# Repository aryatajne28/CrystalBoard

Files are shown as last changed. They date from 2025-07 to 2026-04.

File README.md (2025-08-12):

# CrystalBoard

## A Mechanical Keyboard with clear acrylic case
I always wanted to make a mechanical keyboard using some stacked transparent Acrylic Sheets.
- It now has per key RGB Lights.
- Featuring a Stacked Acrylic Case with minimalistic design.

## Overall CAD Design:
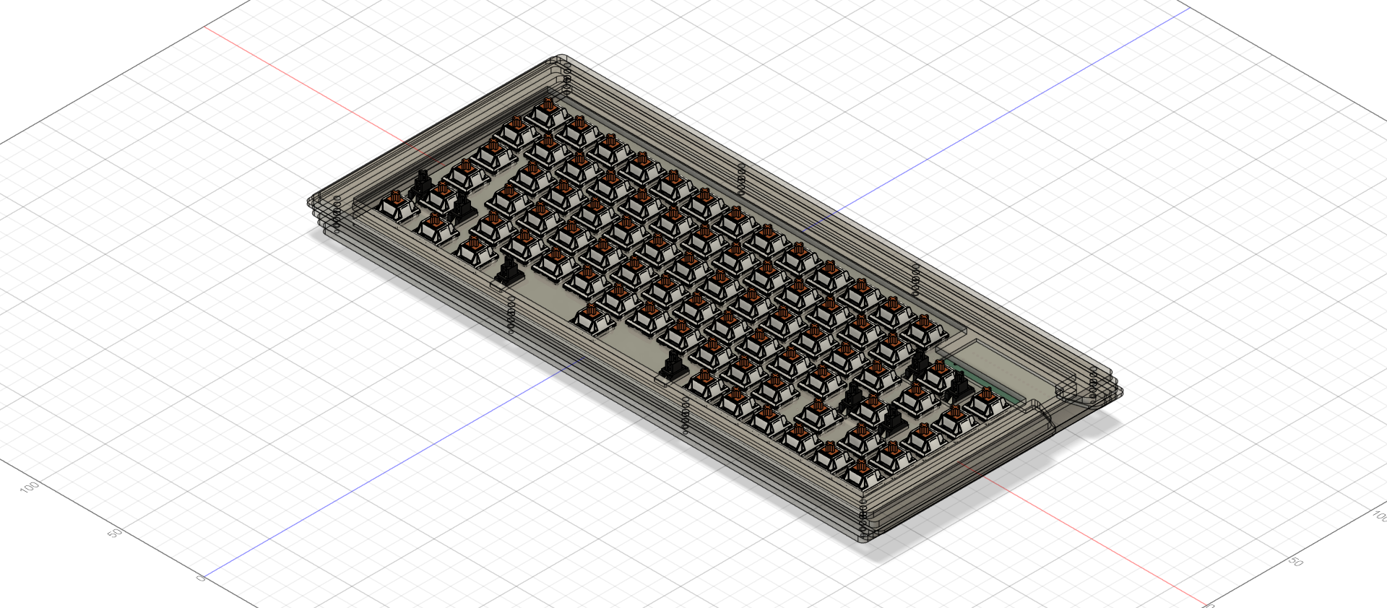
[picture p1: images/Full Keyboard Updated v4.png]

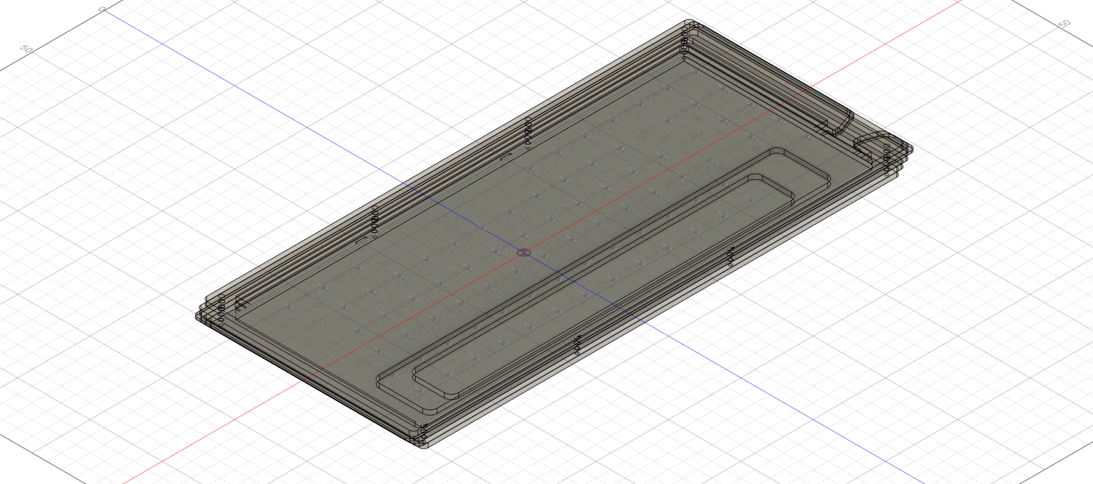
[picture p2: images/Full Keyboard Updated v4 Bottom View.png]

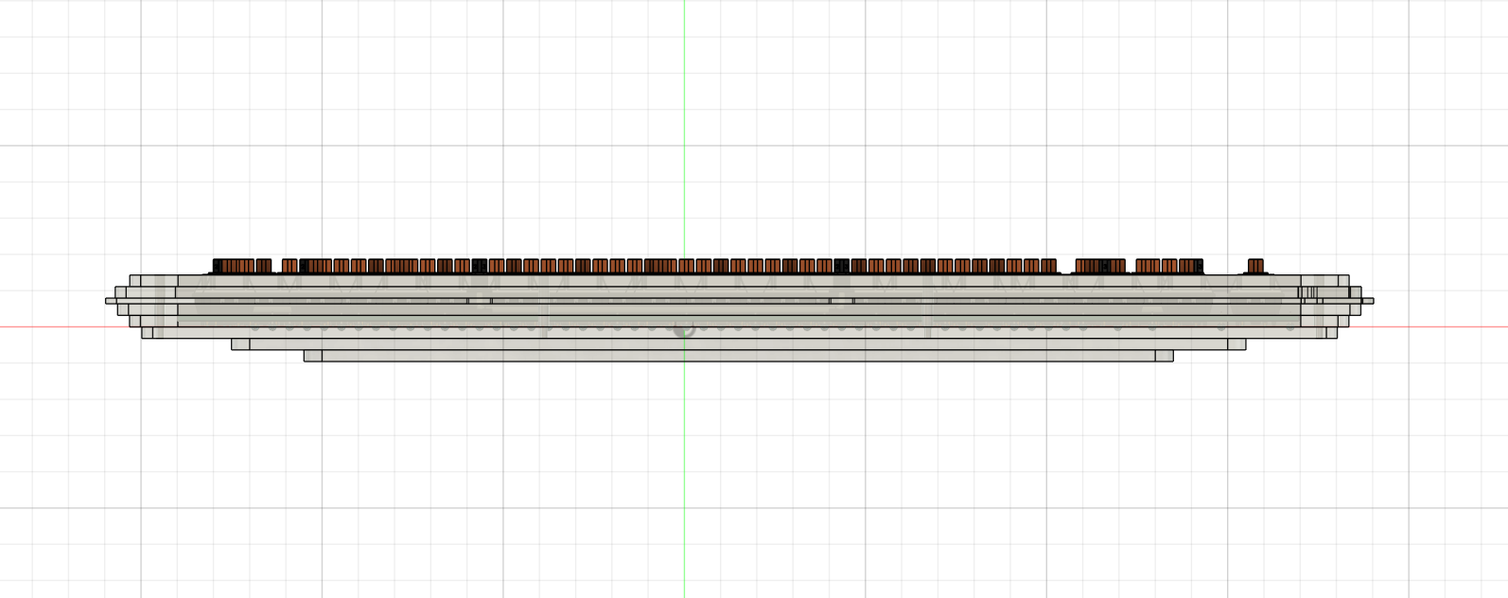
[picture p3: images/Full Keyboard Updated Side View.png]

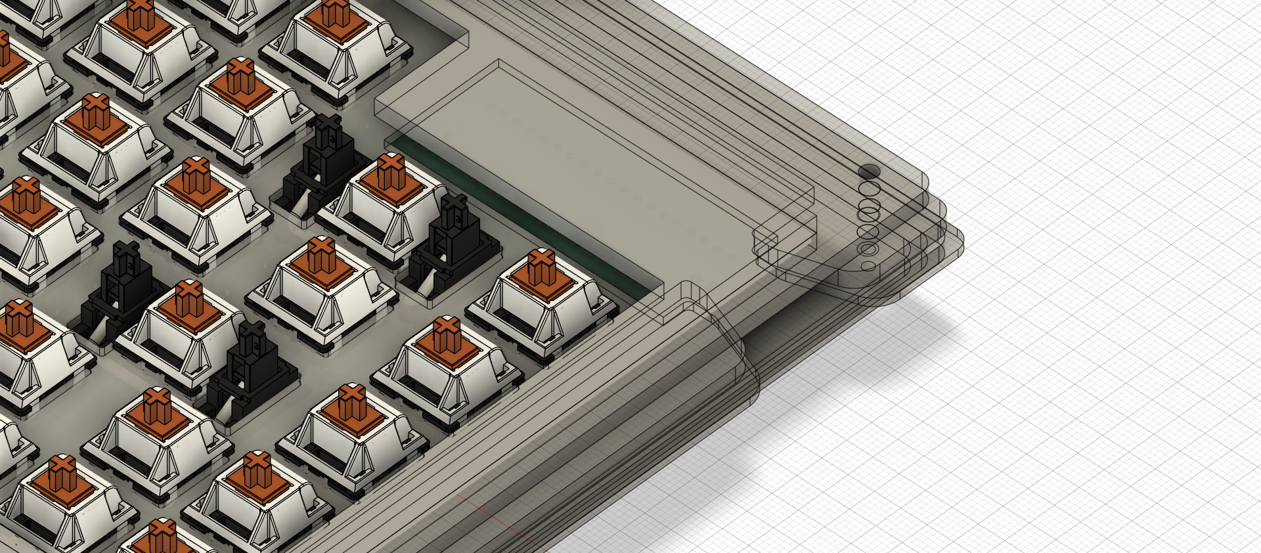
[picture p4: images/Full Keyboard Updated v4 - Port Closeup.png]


## PCB Design
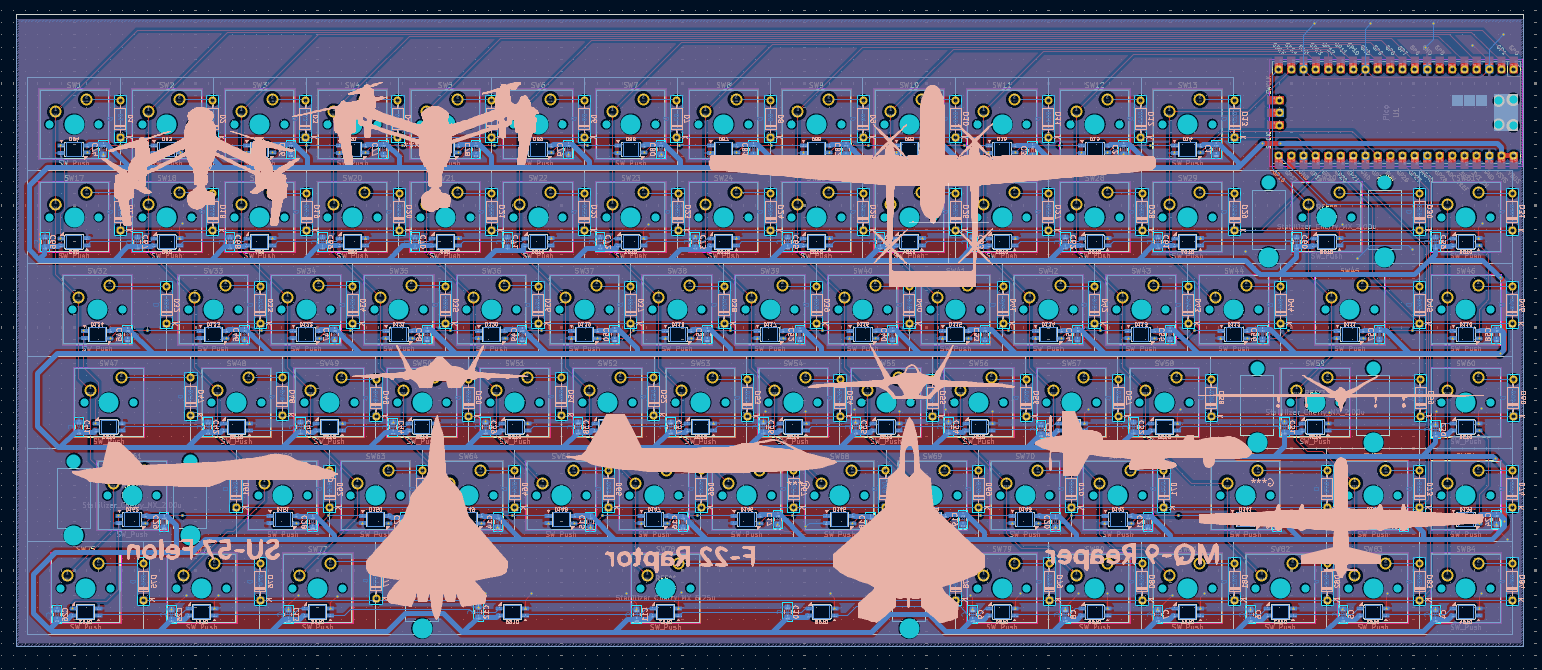
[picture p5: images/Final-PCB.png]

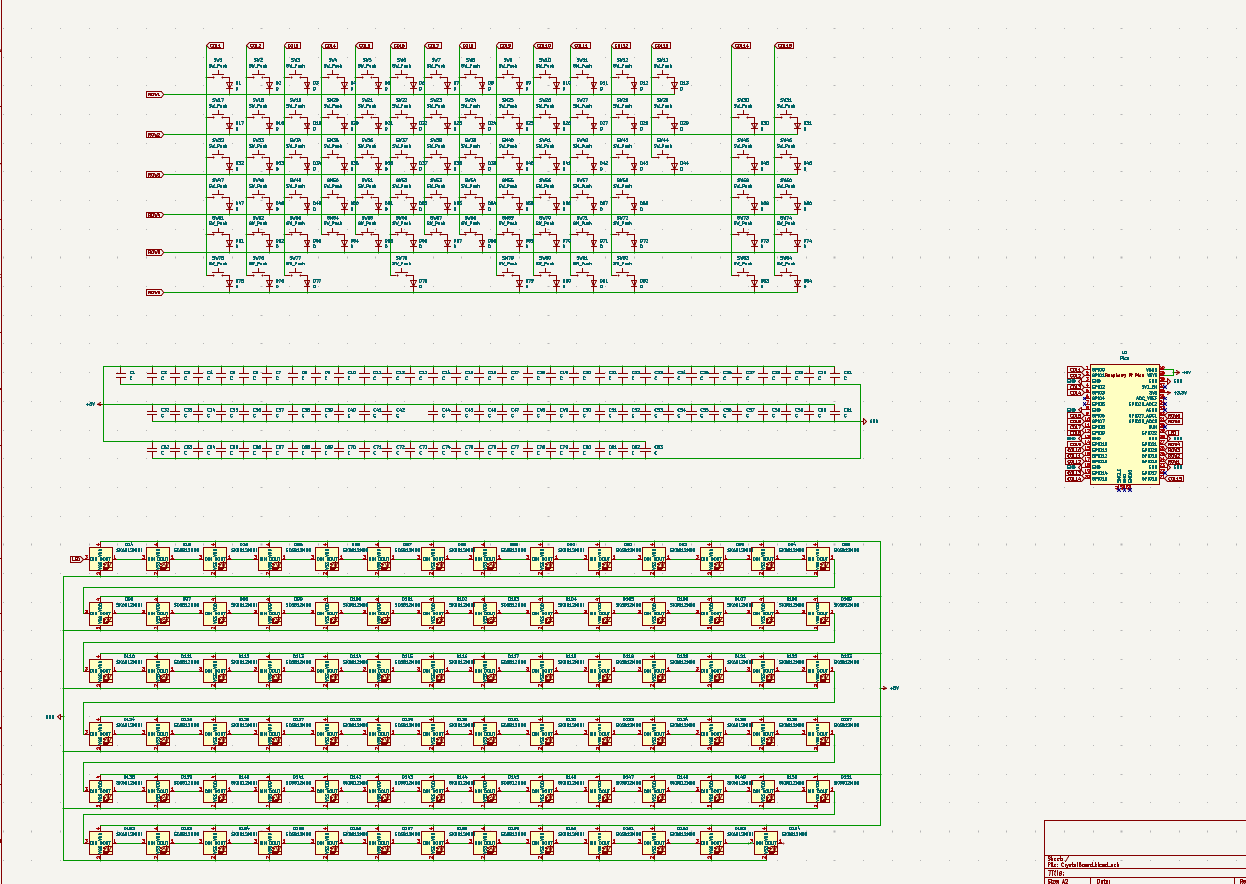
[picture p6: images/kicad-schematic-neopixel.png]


##  BOM List:
https://docs.google.com/spreadsheets/d/18xa4JLoS0O1zEA5zLQhojN7E5wao-EmZjV8RXe0JSpA/
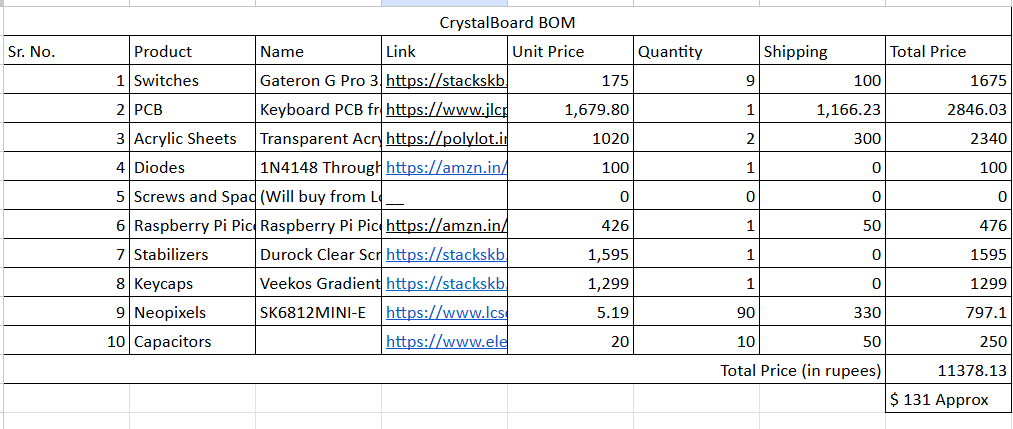
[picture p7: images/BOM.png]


- The CAD output is not what it will look like in real life, it will turn out really cool I can assure!

- Total Time Spent: 16 hours!

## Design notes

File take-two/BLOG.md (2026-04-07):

# My experience with making of the CrystalBoard.

## Assembly
First let's go through the assembly and making of CrystalBoard
- I had cut the acrylic sheets from my school's laser cutter.
- So, I layed out some of the switches onto the acrylic plate to check whether it cutouts match with the PCB or not.

|   |  | |
| - | - | -|

- Since they were matching, I went ahead and soldered the Pi Pico to my PCB and screwed in the stablizers.

|  |   |
| - | - |

- Thus, the next step I did was to solder all the switches and rest of the components in the back of the PCB!

||  |
| - | - |

- After this, I was about to solder my Neopixels, then I noticed that the pins are not matching. I quickly opened my Kicad file and checked and whoosh! I used the wrong footprint :)
- Thus, I was left with no choice but to assemble without them! And after assembling all the rest of the sheets and keycaps, we have our Crystalboard:

|  |  |
| -|-|

## Firmware
I used QMK for this, since I consider it to be a very standard firmware for it's features like: the keyboard isn't detected as a new USB device everytime we plug it in
and direct build loading onto our MCU!

## Why this project didn't work?
- Used wrong footprint for Neopixels (sk6812mini instead of sk6812mini-e).
- I didn't calculate the placement of Micro-USB port of Pico, and due to which, the USB-port broke-off from the pico after short usage while flashing the firmware!
- I didn't have tolerances for screws holes I made in acrylic sheet, due to which the screws didn't go through, I had to use glue temporarily.

## My two cents for anyone designing a keyboard!
- Maybe try to design a hotswappable design. Because for soldering the switches, you have to first insert the switches through the plate that you will design. So if you want to desolder even one switch, that will become a nightmare!
- Focus very much on the CAD of case design, cause even a slight mis-alignment won't let your PCB fit in!

Demo link: https://youtu.be/TqwXyUNoaCY
P.S. there's nothing much in there cause currently the keyboard is not working!

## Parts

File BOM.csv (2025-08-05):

CrystalBoard BOM
Sr. No. | Product | Name | Link | Unit Price | Quantity | Shipping | Total Price
1 | Switches | Gateron G Pro 3.0 Brown KS-9 Tactile Switch (Pack of 10) | https://stackskb.com/store/gateron-g-pro-3-0-brown-ks-9-tactile-switch-pack-of-10/ | 175 | 9 | 100 | 1675
2 | PCB | Keyboard PCB from JLCPCB | https://www.jlcpcb.com/ | 1,679.80 | 1 | 1,166.23 | 2846.03
3 | Acrylic Sheets | Transparent Acrylic Sheets 4ft * 2ft | https://polylot.in/online-store-acrylic-polycarbonate-sheet-buy-online-iindia/acrylicsheet/acrylic-sheets/ | 1020 | 2 | 300 | 2340
4 | Diodes | 1N4148 Through Holes | https://amzn.in/d/j3eLvoh | 100 | 1 | 0 | 100
5 | Screws and Spacers | (Will buy from Local Hardware Shop) | __ | 0 | 0 | 0 | 0
6 | Raspberry Pi Pico | Raspberry Pi Pico | https://amzn.in/d/0y7kWCl | 426 | 1 | 50 | 476
7 | Stabilizers | Durock Clear Screw-In Stabilizers V2 | https://stackskb.com/store/durock-smokey-screw-in-stabilizers-v2/ | 1,595 | 1 | 0 | 1595
8 | Keycaps | Veekos Gradient Keycaps (Cherry Profile) (135 keys) | https://stackskb.com/store/veekos-gradient-keycaps-cherry-profile-135-keys/ | 1,299 | 1 | 0 | 1299
9 | Neopixels | SK6812MINI-E | https://www.lcsc.com/product-detail/C5149201.html | 5.19 | 90 | 330 | 797.1
Total Price |  |  |  |  |  |  | 11128.13 | (in rupees)
 |  |  |  |  |  |  | $ 127 Approx

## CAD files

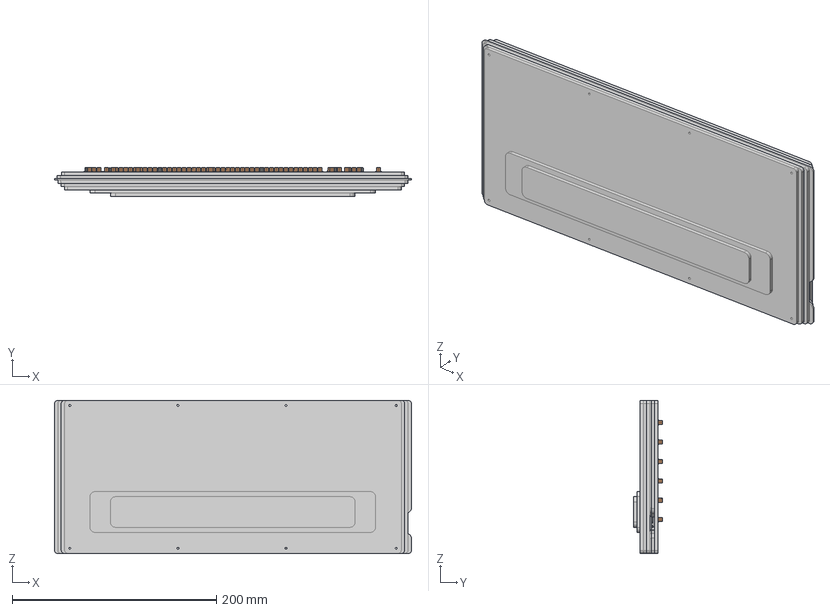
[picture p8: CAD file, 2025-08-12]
CAD/Full Keyboard Updated_.step
350.0 x 28.2 x 150.3 mm
SW_Cherry_MX_PCB x 81
Stabilizer_Cherry_MX_2.00u x 3
Stabilizer_Cherry_MX_6.25u
D_DO-35_SOD27_P7.62mm_Horizontal x 81

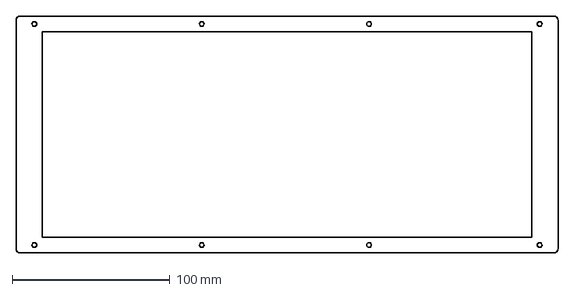
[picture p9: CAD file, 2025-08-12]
case/ClosedSpacerLevel2.dxf
343.2 x 150.0 mm

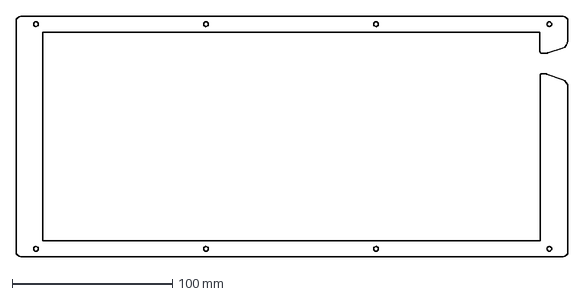
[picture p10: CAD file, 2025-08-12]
case/OpenSpacerLevel4.dxf
344.0 x 150.0 mm

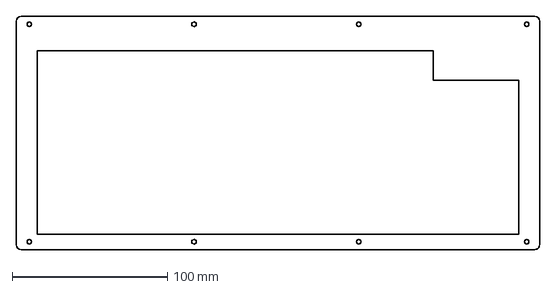
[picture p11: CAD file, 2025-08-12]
Production/LaserCutting/TopSpacerLevel6.dxf
336.6 x 150.0 mm

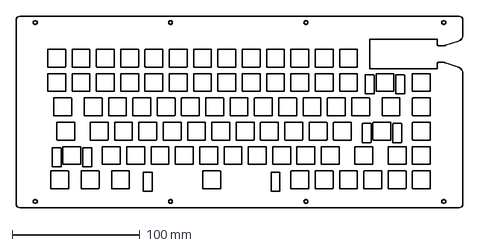
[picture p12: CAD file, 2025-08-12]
case/SwitchPlateV2.dxf
350.0 x 150.0 mm

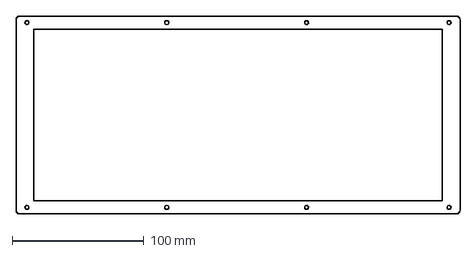
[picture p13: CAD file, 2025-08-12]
Production/LaserCutting/ClosedSpacerLevel1.dxf
336.6 x 150.0 mm

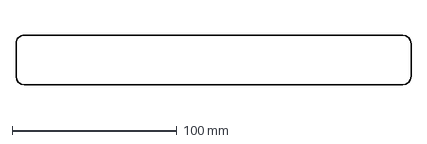
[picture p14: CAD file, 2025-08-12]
Production/LaserCutting/StandLevel0.dxf
240.0 x 30.0 mm

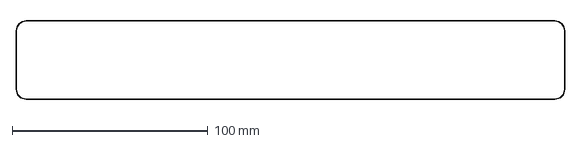
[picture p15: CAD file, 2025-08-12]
Production/LaserCutting/StandLevel1.dxf
280.0 x 40.0 mm

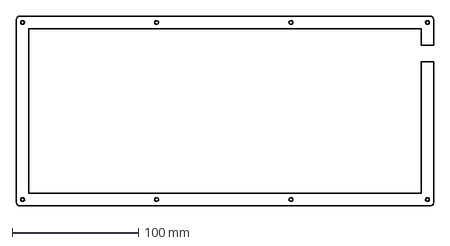
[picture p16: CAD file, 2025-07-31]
Production/LaserCutting/OpenSpacer.dxf
330.0 x 150.0 mm

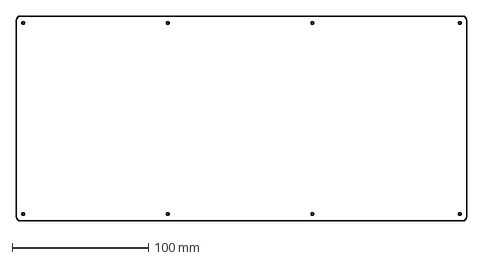
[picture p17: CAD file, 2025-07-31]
Production/LaserCutting/Bottom.dxf
330.0 x 150.0 mm

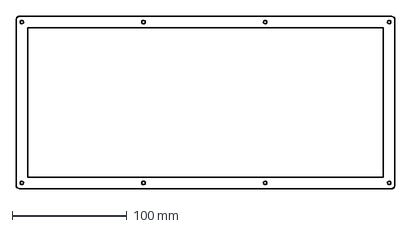
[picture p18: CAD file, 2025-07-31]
Production/LaserCutting/ClosedSpacer.dxf
330.0 x 150.0 mm

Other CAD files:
Production/LaserCutting/SwitchPlate.dxf

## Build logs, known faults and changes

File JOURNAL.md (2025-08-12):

# Journal for CrystalBoard

- Date 26/07/25 - Total Time Spent: 0.5 hours
    - Idea: Make a custom mechanical keyboard with case made up of clear acrylic sheets stacked on top of each other, thus the name crystal board!
    - Work done - Finalised the layout, took it from keyboard-layout-editor.com and drawn all the rows and columns on that layout!
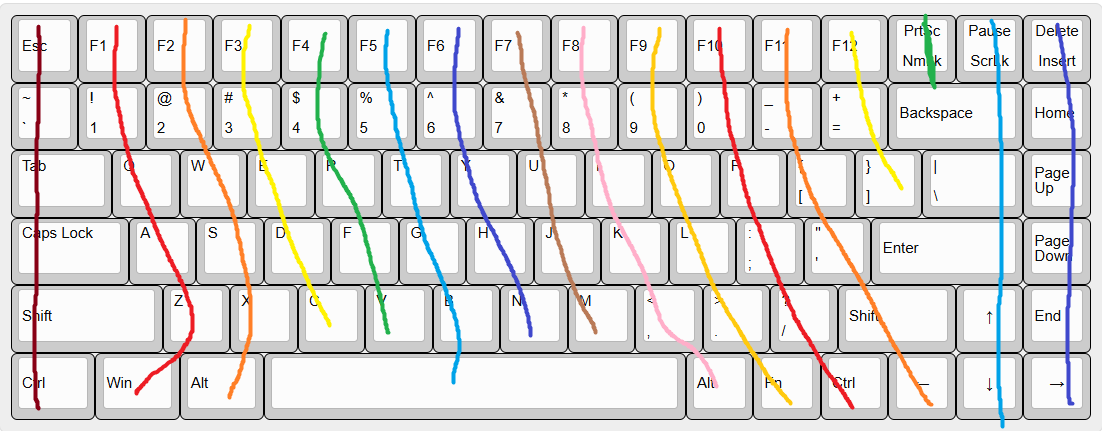
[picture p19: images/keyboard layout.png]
Keyboard Layout
    
    - Setup Kicad with all the libraries and footprints.
    - Time Spent - 30 mins
    
- Date 27/07/25 - Total Time Spent: 4.5 hours
    - I made the complete schematic made the PCB layout but then I noticed that there is no space for Pi Pico. So I deleted the top right 3 keys, thus I had to do changes in the Kicad Schematic and PCB. Thus took some time but I am done with PCB routing. Now I am thinking to add some neopixels and some silkscreen to the PCB.
    - The updated keyboard layout looks like this now:
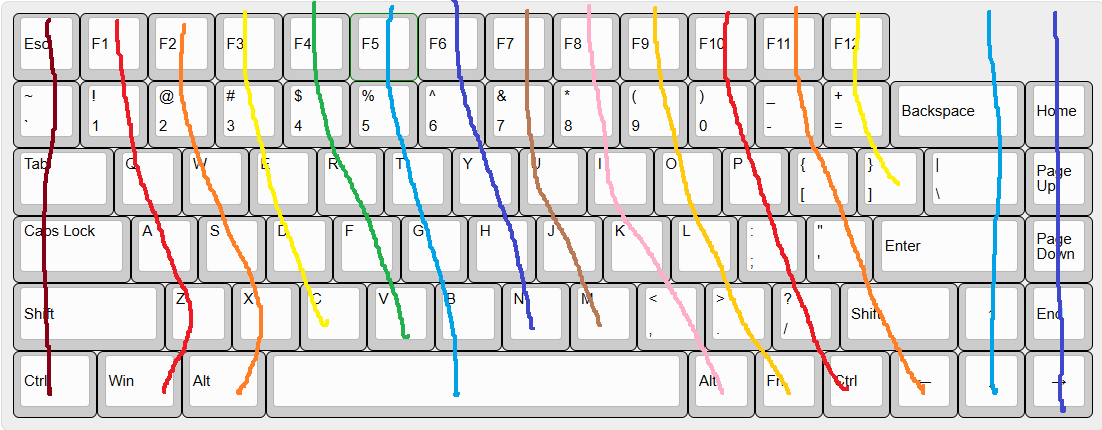
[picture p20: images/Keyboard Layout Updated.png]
Keyboard Layout Updated
    
    - Kicad Schematic and PCB:
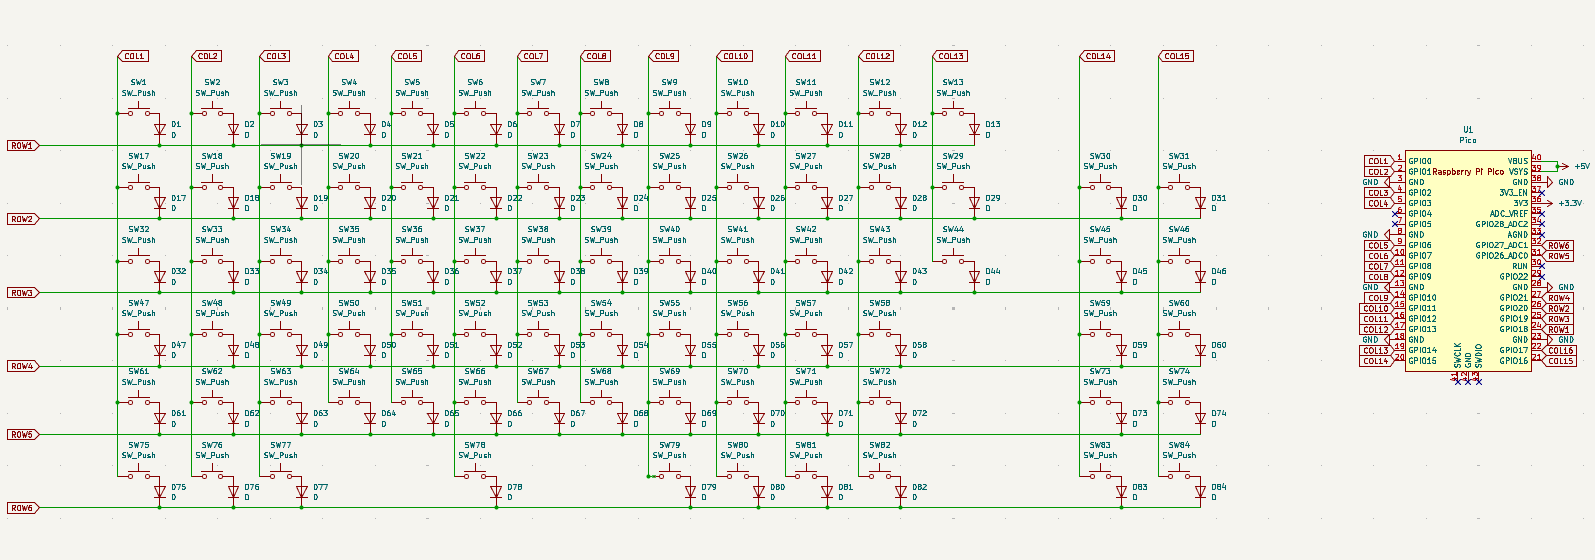
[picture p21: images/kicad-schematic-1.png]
Kicad Schematic
    
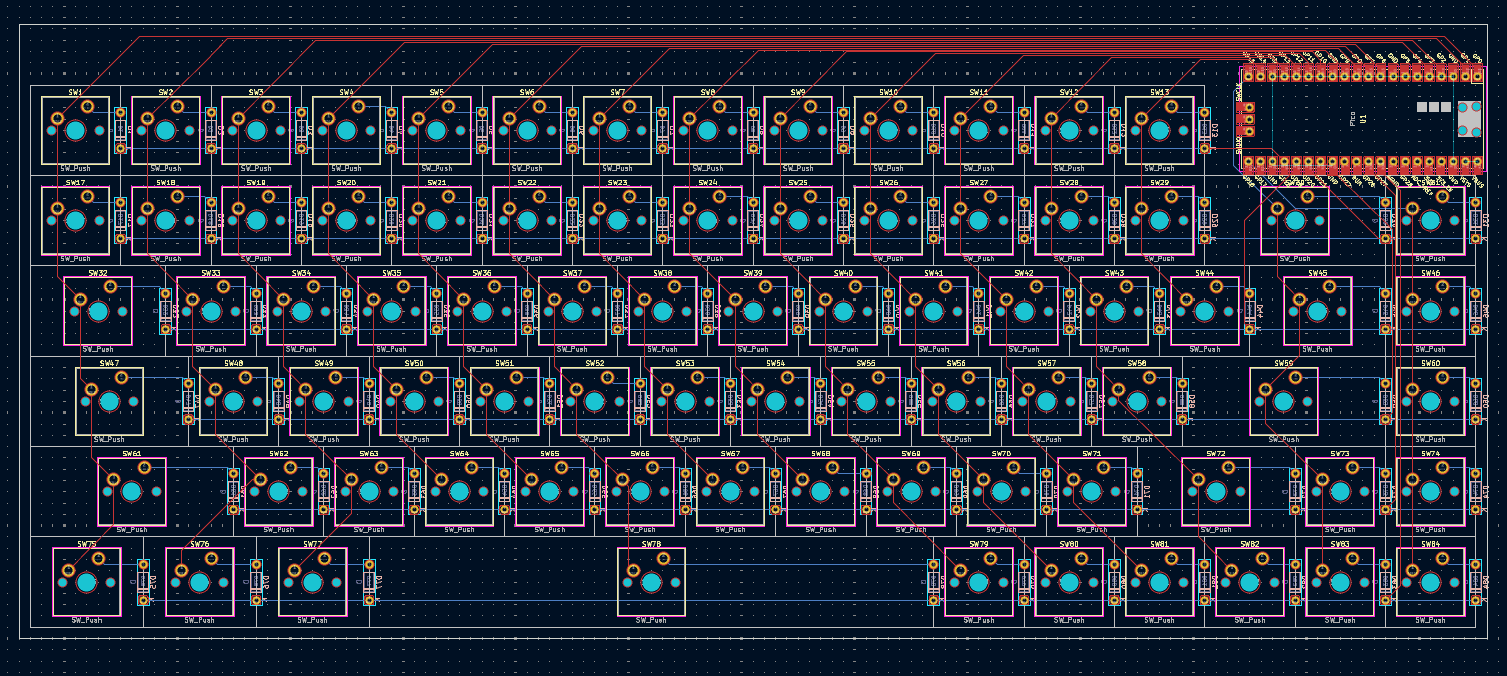
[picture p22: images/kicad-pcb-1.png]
Kicad PCB
    
    - Things to do next - Put some Neopixels, Stabilizers, Plate, Silkscreen
    - Time Spent today till now - 3 hours

- Date 27/07/25 (Update 2)
    - Done with the Neopixels, I did not add per key LED but a bar on top and on WASD keys (not for gaming obviously :O)
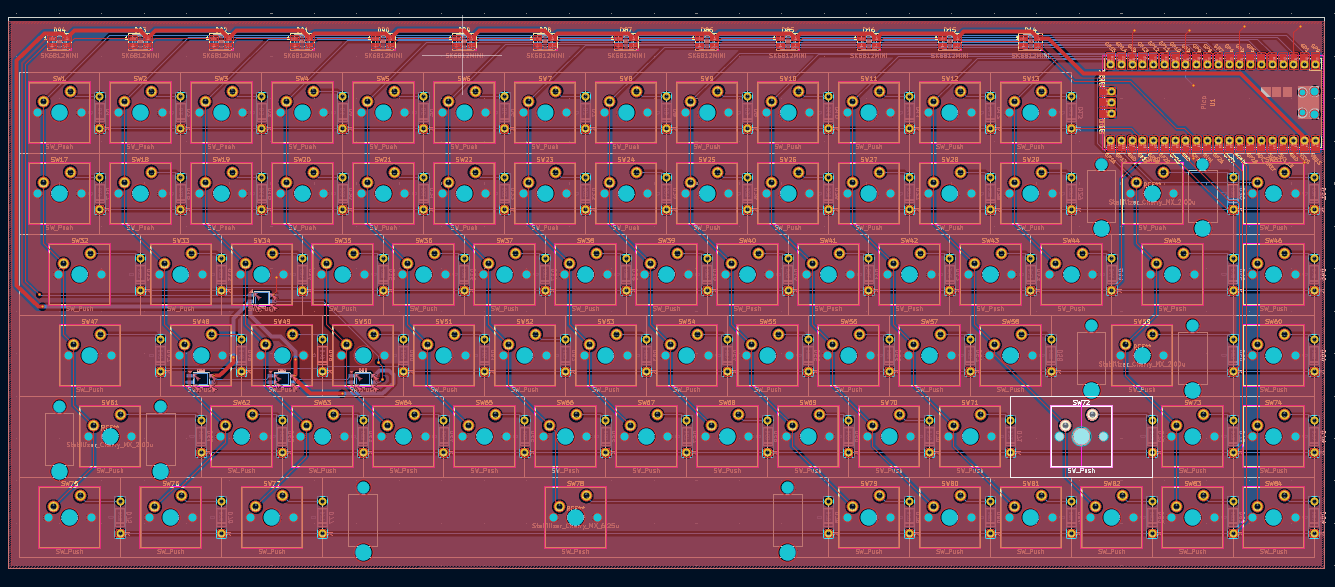
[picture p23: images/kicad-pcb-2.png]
    
    - Time Spent - 1.5 hours

- Date 28/07/25 - Total Time Spent: 1.5 hours
    - Done with Silkscreen and Stablizers.
    - It was pain to convert the images into B&W vectors.
    - PCB Looks like this now:
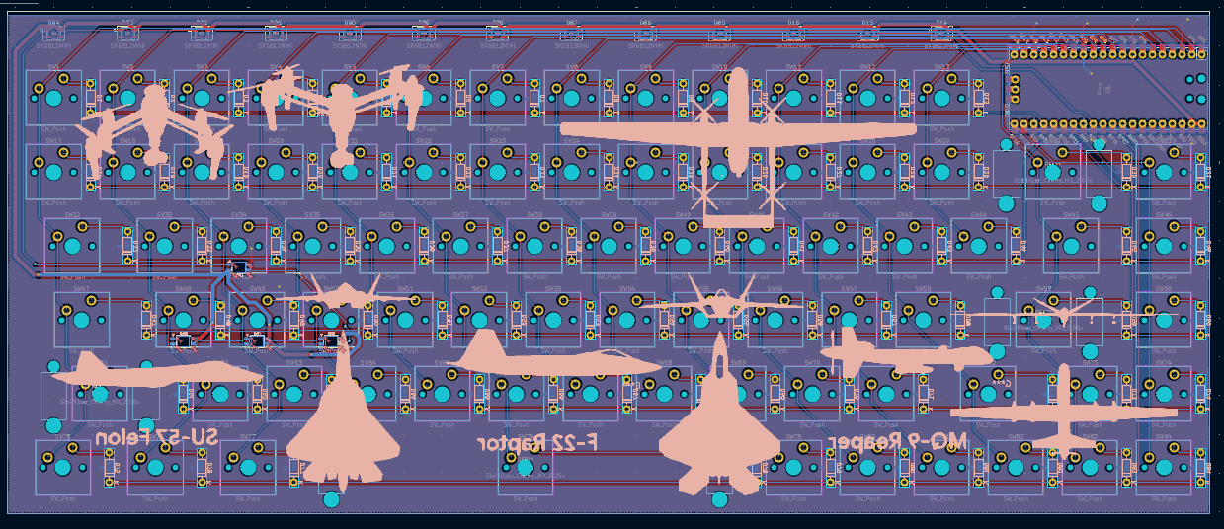
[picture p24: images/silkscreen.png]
    
    - Time spent - 1.5 hours

- Date 31/07/25 - Total Time Spent: 5 hours
    - Speedrunning the Case and Code File!
    - Case I have designed as layers since I will be laser cutting the acrylic sheets.
    - For illustration purposes I have just reduced the opacity of the components in Autocad to make it look like Acrylic, but in real life it will look really good!
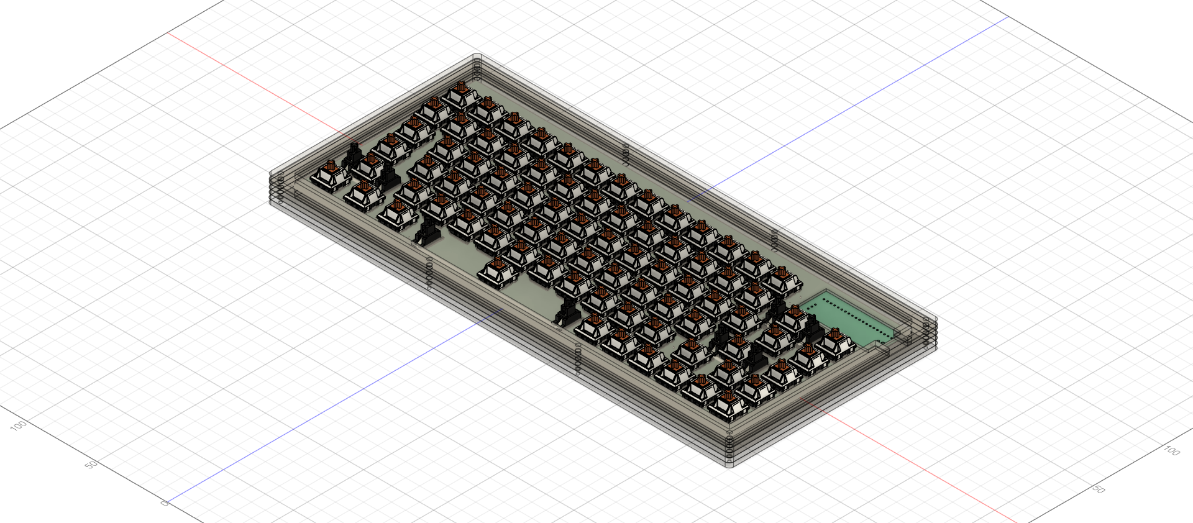
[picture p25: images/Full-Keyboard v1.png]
    
    - Time spent - 3 hours

    - Finalized the repo and collected resources for all the BOM.
    - Time Spent - 2 hours

- Date 03/08/25 - Total Time Spent: 2 hours
    - According to the changes suggested by @Kai Pereira(Slack) I have now added per key RGB Neopixel!
    - So I deleted all the tracks because it was a lot of hassle to shift everything and again route.
    - Added 83x Neopixels and 83x 0805 Capacitors in the schematic and now searching for good site to order from, because ordering to India is a hassle
    - New Schematic and PCB photo:
    
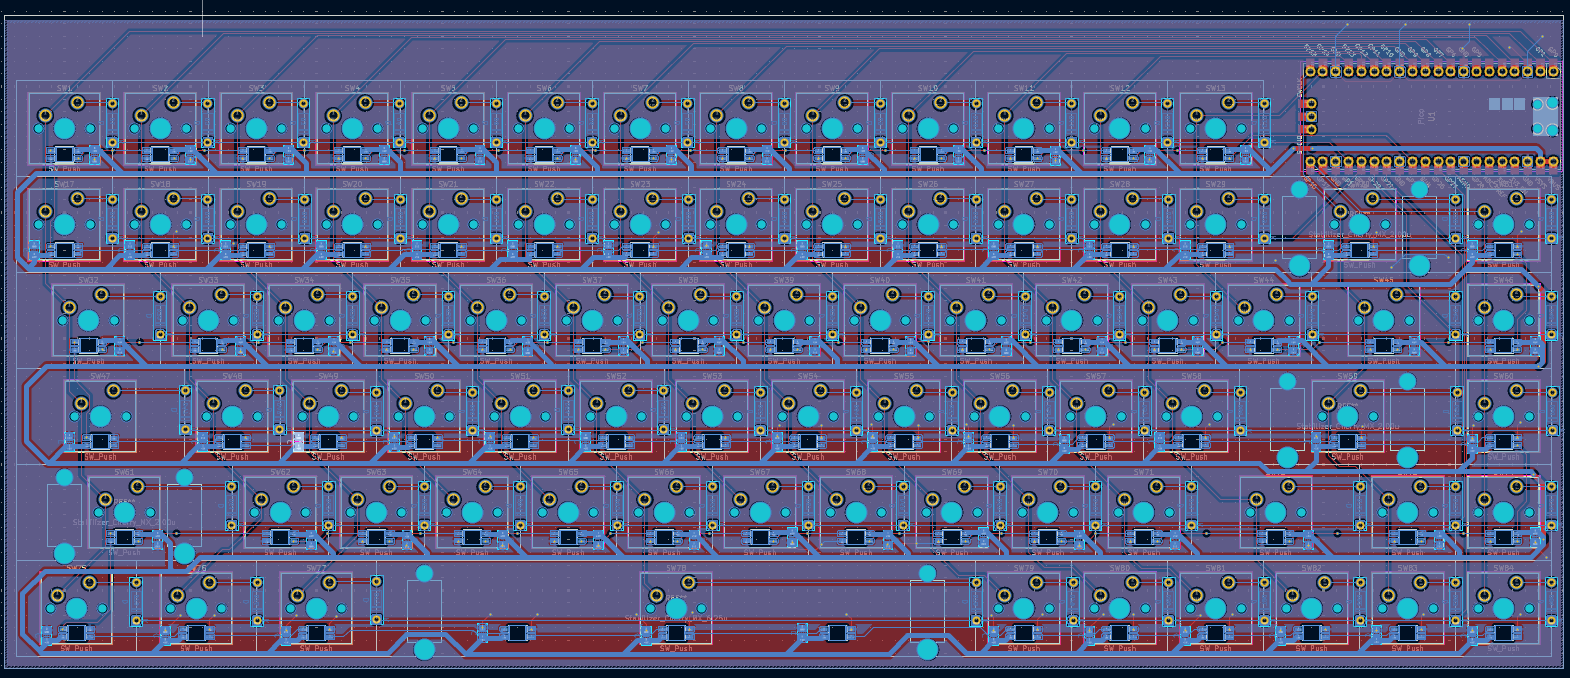
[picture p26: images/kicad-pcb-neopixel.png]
    
    - Todo: Code change and Update BOM
    - Time Spent - 2 hours

- Date 06/08/25 - Total Time Spent: 0.5 hours
    - I have added the updated items in my BOM and updated the code a bit.
    - Refinded the README.md file.
    - Another Update, I uploaded the new Kicad Project files and the production .zip folder for the same.
    - Time Spent - 0.5 hours

- Date 12/08/25 - Total Time Spent: 2 hours
    - According to the changes suggested by Kai, I have made the case a bit more complex.
    - I took referrence from this design I found online: https://www.ponoko.com/blog/maker-success-stories/limbo-keys-custom-mechanical-keyboards/
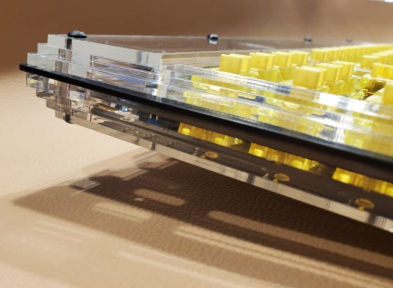
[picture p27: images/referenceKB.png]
    - Reference images: 
    - What I did in Fusion:
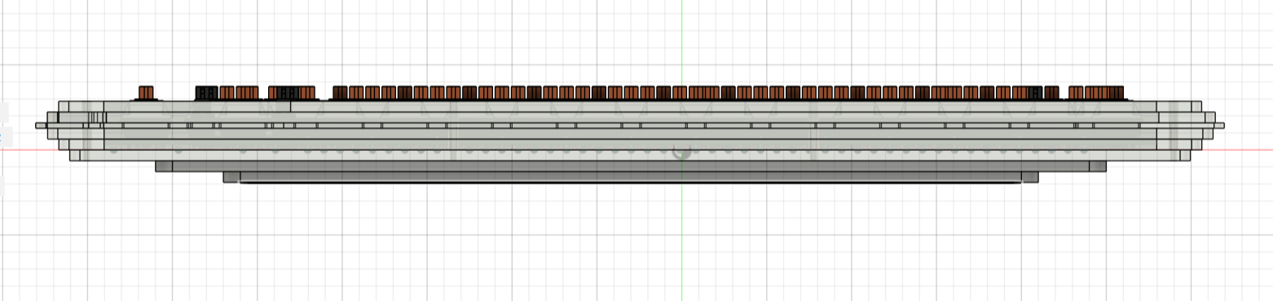
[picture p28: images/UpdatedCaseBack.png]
    
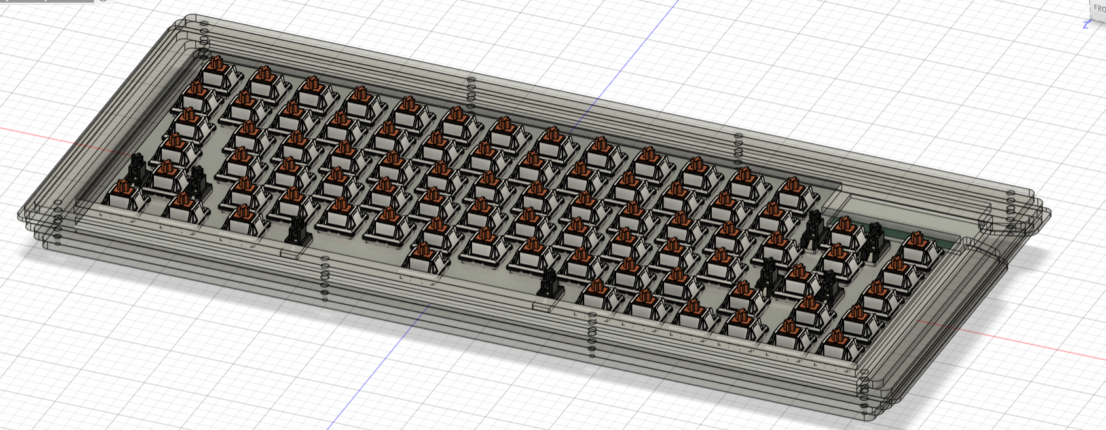
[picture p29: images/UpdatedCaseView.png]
    
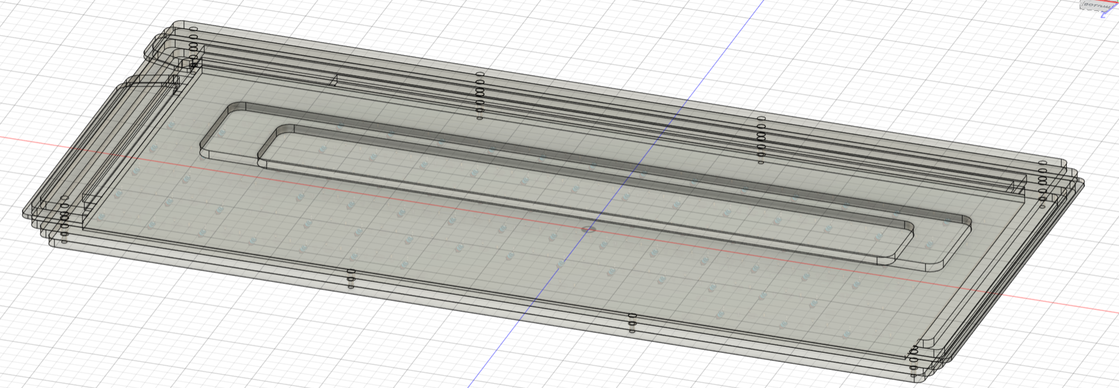
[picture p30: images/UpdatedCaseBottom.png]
    

    - Now it has a stand below for a tilted design, which is just two cutouts of leftover acrylic and I will stick them using clear glue.
    - BOM remains the same.
    - Time Spent - 2 hours

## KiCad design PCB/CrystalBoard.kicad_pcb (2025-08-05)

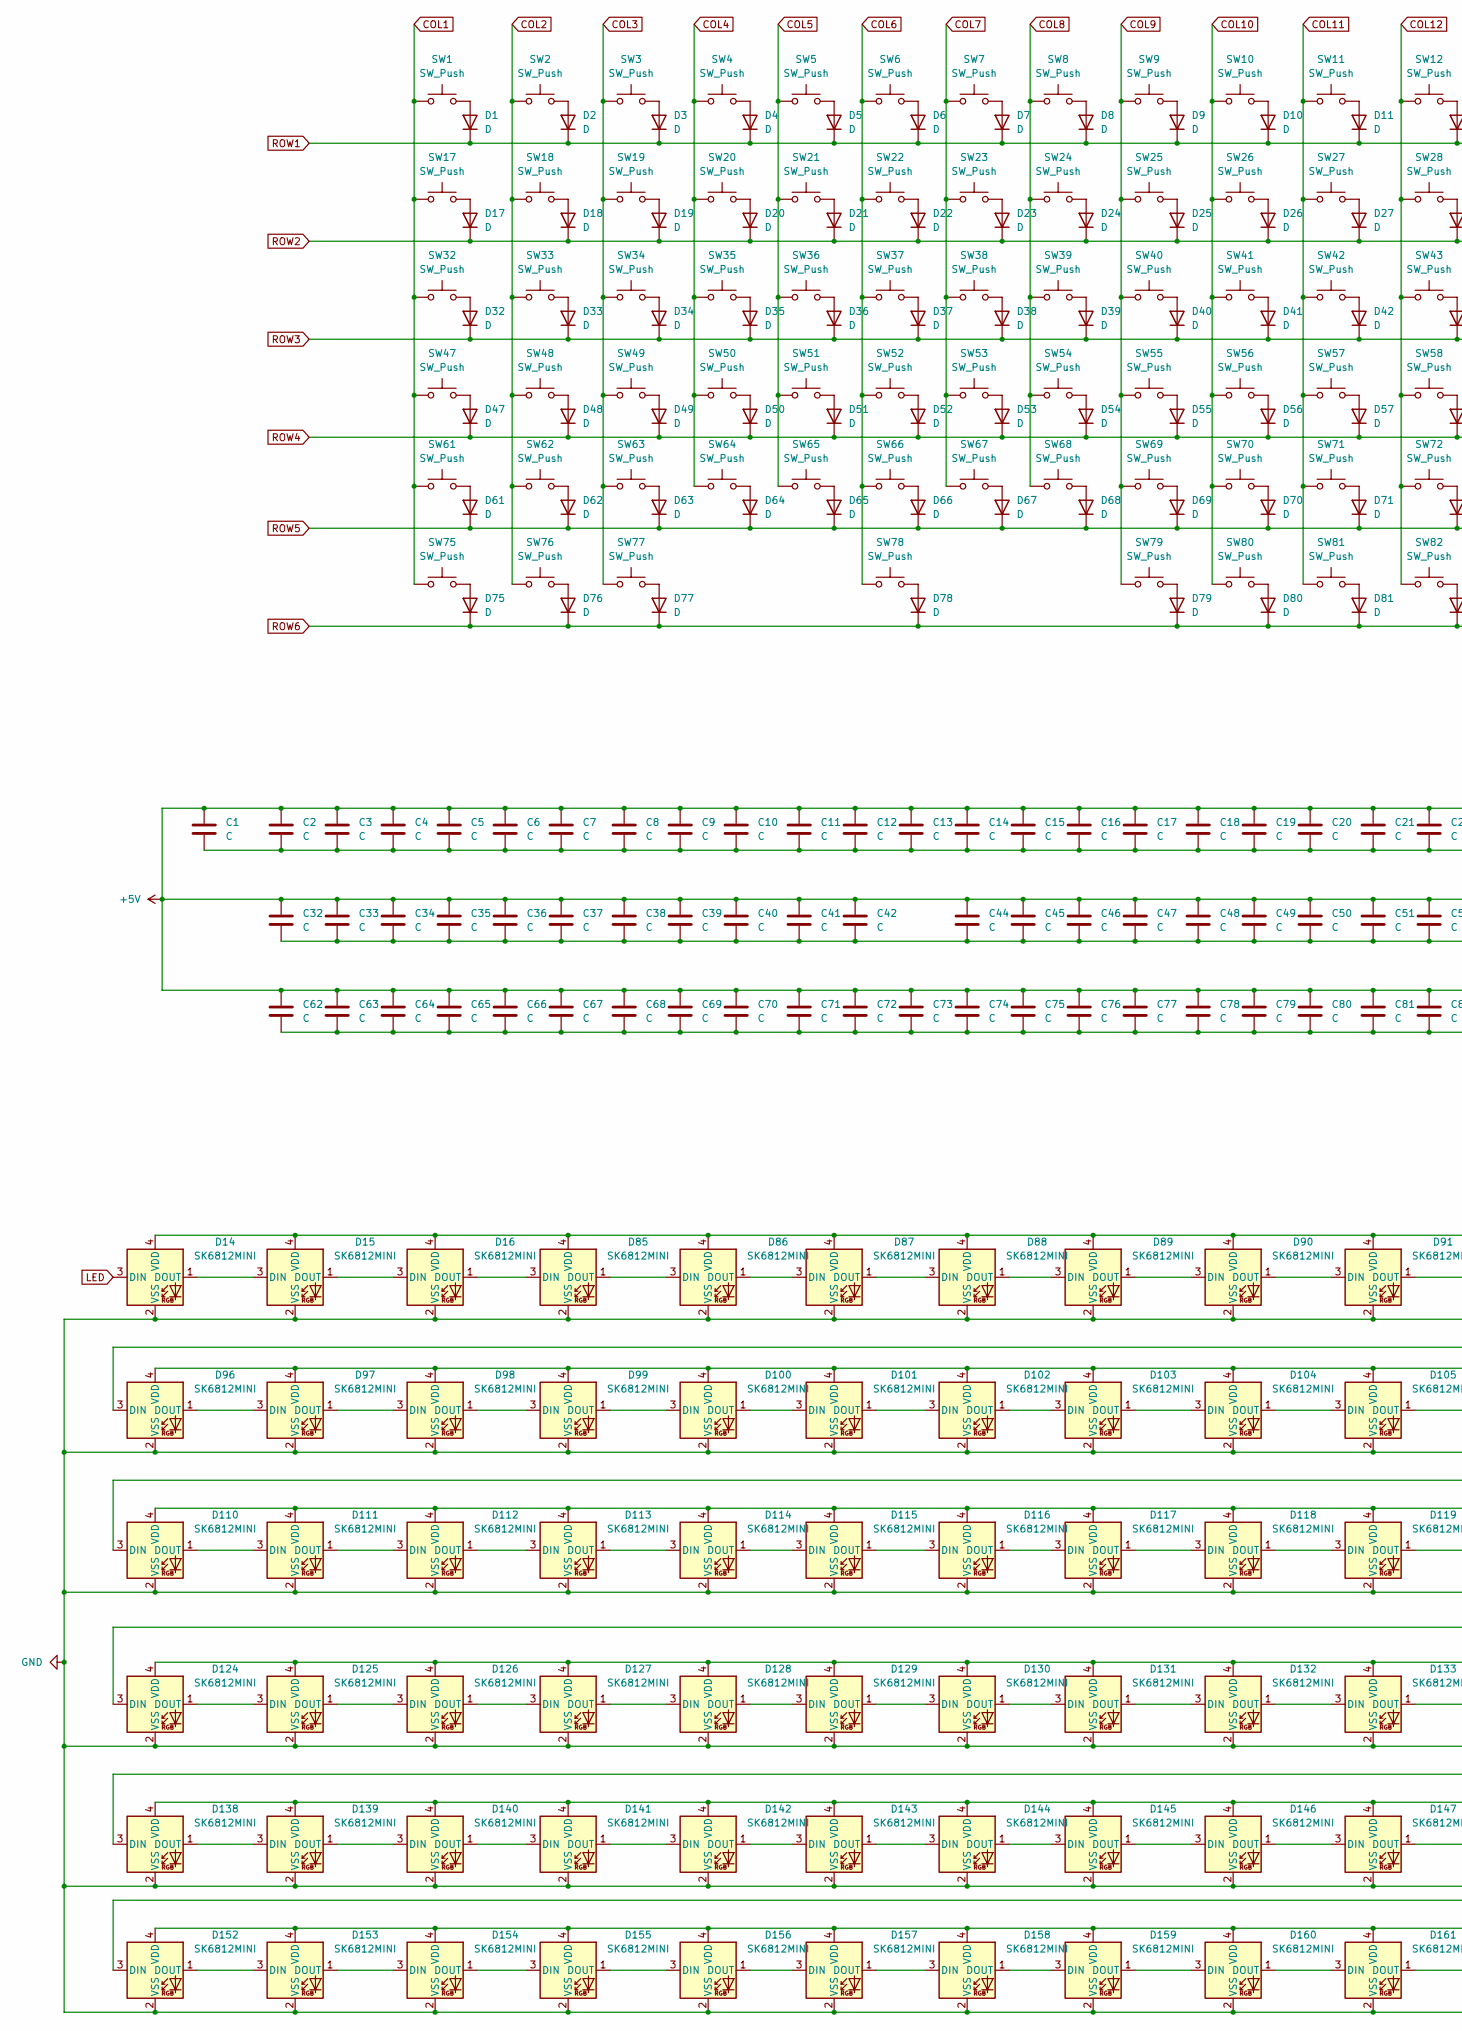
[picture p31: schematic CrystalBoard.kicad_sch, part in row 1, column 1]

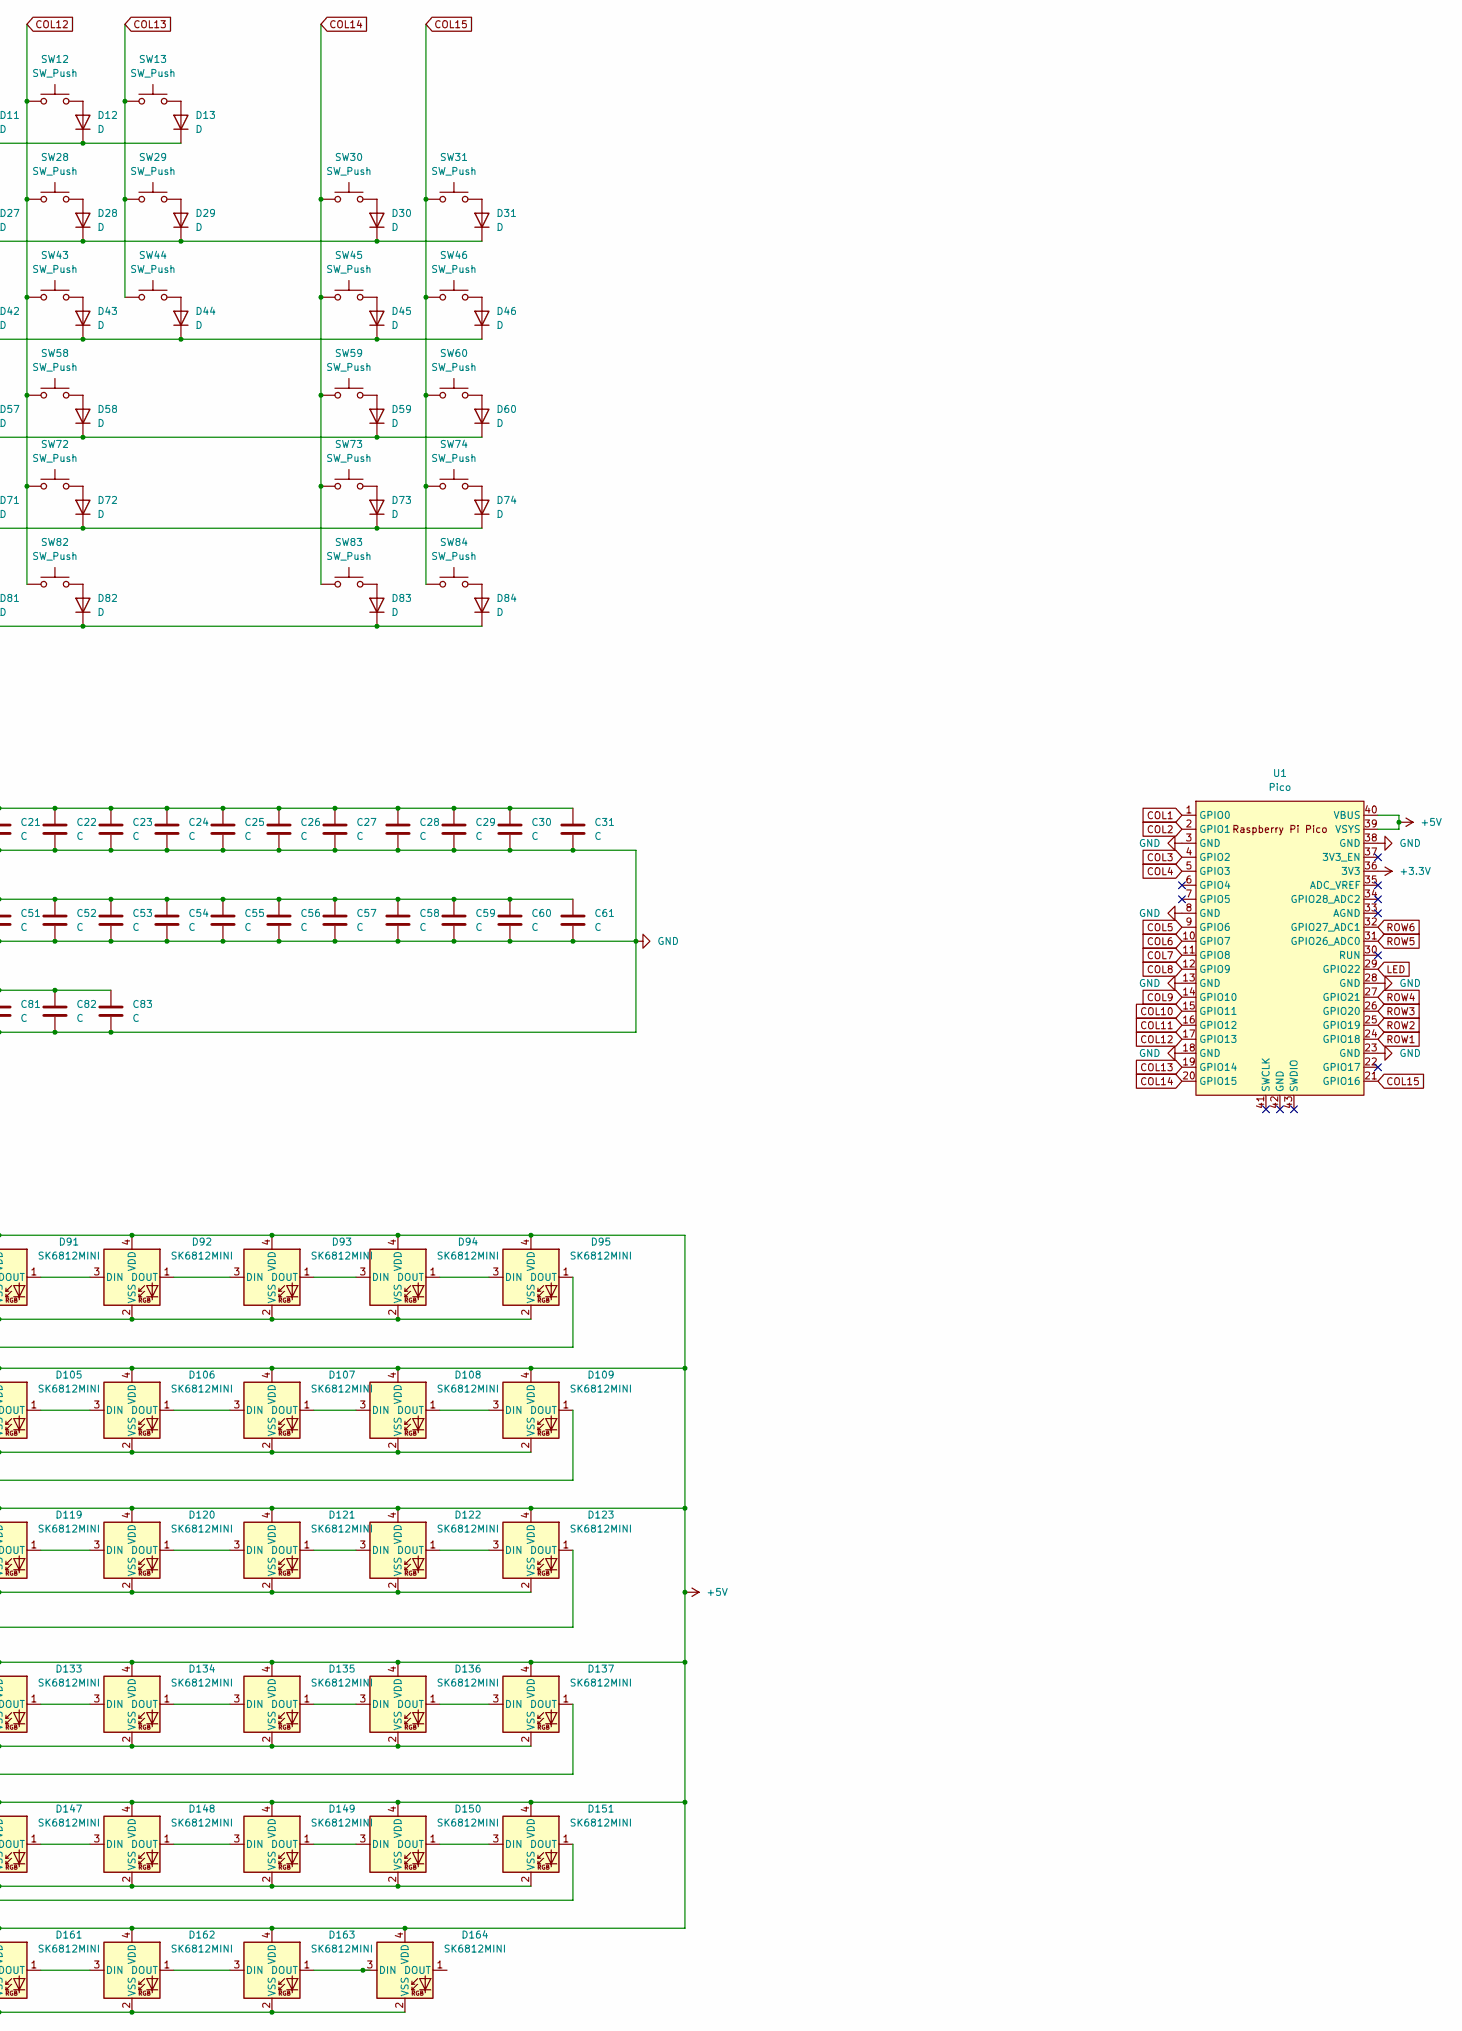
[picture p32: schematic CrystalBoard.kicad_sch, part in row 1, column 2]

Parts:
C1, C2, C3, C4, C5, C6, C7, C8, C9, C10, C11, C12, C13, C14, C15, C16, C17, C18, C19, C20, C21, C22, C23, C24, C25, C26, C27, C28, C29, C30, C31, C32, C33, C34, C35, C36, C37, C38, C39, C40, C41, C42, C44, C45, C46, C47, C48, C49, C50, C51, C52, C53, C54, C55, C56, C57, C58, C59, C60, C61, C62, C63, C64, C65, C66, C67, C68, C69, C70, C71, C72, C73, C74, C75, C76, C77, C78, C79, C80, C81, C82, C83: C; C_0805_2012Metric_Pad1.18x1.45mm_HandSolder
D1, D2, D3, D4, D5, D6, D7, D8, D9, D10, D11, D12, D13, D17, D18, D19, D20, D21, D22, D23, D24, D25, D26, D27, D28, D29, D30, D31, D32, D33, D34, D35, D36, D37, D38, D39, D40, D41, D42, D43, D44, D45, D46, D47, D48, D49, D50, D51, D52, D53, D54, D55, D56, D57, D58, D59, D60, D61, D62, D63, D64, D65, D66, D67, D68, D69, D70, D71, D72, D73, D74, D75, D76, D77, D78, D79, D80, D81, D82, D83, D84: D; D_DO-35_SOD27_P7.62mm_Horizontal
D14, D15, D16, D85, D86, D87, D88, D89, D90, D91, D92, D93, D94, D95, D96, D97, D98, D99, D100, D101, D102, D103, D104, D105, D106, D107, D108, D109, D110, D111, D112, D113, D114, D115, D116, D117, D118, D119, D120, D121, D122, D123, D124, D125, D126, D127, D128, D129, D130, D131, D132, D133, D134, D135, D136, D137, D138, D139, D140, D141, D142, D143, D144, D145, D146, D147, D148, D149, D150, D151, D152, D153, D154, D155, D156, D157, D158, D159, D160, D161, D162, D163, D164: SK6812MINI; SK6812-MINI-E
SW1, SW2, SW3, SW4, SW5, SW6, SW7, SW8, SW9, SW10, SW11, SW12, SW13, SW17, SW18, SW19, SW20, SW21, SW22, SW23, SW24, SW25, SW26, SW27, SW28, SW29, SW31, SW33, SW34, SW35, SW36, SW37, SW38, SW39, SW40, SW41, SW42, SW43, SW44, SW46, SW48, SW49, SW50, SW51, SW52, SW53, SW54, SW55, SW56, SW57, SW58, SW60, SW62, SW63, SW64, SW65, SW66, SW67, SW68, SW69, SW70, SW71, SW73, SW74, SW79, SW80, SW81, SW82, SW83, SW84: SW_Push; SW_Cherry_MX_PCB_1.00u
SW30: SW_Push; SW_Cherry_MX_PCB_2.00u
SW32, SW45: SW_Push; SW_Cherry_MX_PCB_1.50u
SW47, SW72: SW_Push; SW_Cherry_MX_PCB_1.75u
SW59, SW61: SW_Push; SW_Cherry_MX_PCB_2.25u
SW75, SW76, SW77: SW_Push; SW_Cherry_MX_PCB_1.25u
SW78: SW_Push; SW_Cherry_MX_PCB_6.25u
U1: Pico; RPi_Pico_SMD_TH

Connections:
+3.3V: U1.36 (3V3)
+5V: C1.1, C2.1, C3.1, C4.1, C5.1, C6.1, C7.1, C8.1, C9.1, C10.1, C11.1, C12.1, C13.1, C14.1, C15.1, C16.1, C17.1, C18.1, C19.1, C20.1, C21.1, C22.1, C23.1, C24.1, C25.1, C26.1, C27.1, C28.1, C29.1, C30.1, C31.1, C32.1, C33.1, C34.1, C35.1, C36.1, C37.1, C38.1, C39.1, C40.1, C41.1, C42.1, C44.1, C45.1, C46.1, C47.1, C48.1, C49.1, C50.1, C51.1, C52.1, C53.1, C54.1, C55.1, C56.1, C57.1, C58.1, C59.1, C60.1, C61.1, C62.1, C63.1, C64.1, C65.1, C66.1, C67.1, C68.1, C69.1, C70.1, C71.1, C72.1, C73.1, C74.1, C75.1, C76.1, C77.1, C78.1, C79.1, C80.1, C81.1, C82.1, C83.1, D14.4 (VDD), D15.4 (VDD), D16.4 (VDD), D85.4 (VDD), D86.4 (VDD), D87.4 (VDD), D88.4 (VDD), D89.4 (VDD), D90.4 (VDD), D91.4 (VDD), D92.4 (VDD), D93.4 (VDD), D94.4 (VDD), D95.4 (VDD), D96.4 (VDD), D97.4 (VDD), D98.4 (VDD), D99.4 (VDD), D100.4 (VDD), D101.4 (VDD), D102.4 (VDD), D103.4 (VDD), D104.4 (VDD), D105.4 (VDD), D106.4 (VDD), D107.4 (VDD), D108.4 (VDD), D109.4 (VDD), D110.4 (VDD), D111.4 (VDD), D112.4 (VDD), D113.4 (VDD), D114.4 (VDD), D115.4 (VDD), D116.4 (VDD), D117.4 (VDD), D118.4 (VDD), D119.4 (VDD), D120.4 (VDD), D121.4 (VDD), D122.4 (VDD), D123.4 (VDD), D124.4 (VDD), D125.4 (VDD), D126.4 (VDD), D127.4 (VDD), D128.4 (VDD), D129.4 (VDD), D130.4 (VDD), D131.4 (VDD), D132.4 (VDD), D133.4 (VDD), D134.4 (VDD), D135.4 (VDD), D136.4 (VDD), D137.4 (VDD), D138.4 (VDD), D139.4 (VDD), D140.4 (VDD), D141.4 (VDD), D142.4 (VDD), D143.4 (VDD), D144.4 (VDD), D145.4 (VDD), D146.4 (VDD), D147.4 (VDD), D148.4 (VDD), D149.4 (VDD), D150.4 (VDD), D151.4 (VDD), D152.4 (VDD), D153.4 (VDD), D154.4 (VDD), D155.4 (VDD), D156.4 (VDD), D157.4 (VDD), D158.4 (VDD), D159.4 (VDD), D160.4 (VDD), D161.4 (VDD), D162.4 (VDD), D163.4 (VDD), D164.4 (VDD), U1.39 (VSYS), U1.40 (VBUS); also elsewhere on the board
COL1: SW1.1, SW17.1, SW32.1, SW47.1, SW61.1, SW75.1, U1.1 (GPIO0)
COL2: SW2.1, SW18.1, SW33.1, SW48.1, SW62.1, SW76.1, U1.2 (GPIO1)
COL3: SW3.1, SW19.1, SW34.1, SW49.1, SW63.1, SW77.1, U1.4 (GPIO2)
COL4: SW4.1, SW20.1, SW35.1, SW50.1, SW64.1, U1.5 (GPIO3)
COL5: SW5.1, SW21.1, SW36.1, SW51.1, SW65.1, U1.9 (GPIO6)
COL6: SW6.1, SW22.1, SW37.1, SW52.1, SW66.1, SW78.1, U1.10 (GPIO7)
COL7: SW7.1, SW23.1, SW38.1, SW53.1, SW67.1, U1.11 (GPIO8)
COL8: SW8.1, SW24.1, SW39.1, SW54.1, SW68.1, U1.12 (GPIO9)
COL9: SW9.1, SW25.1, SW40.1, SW55.1, SW69.1, SW79.1, U1.14 (GPIO10)
COL10: SW10.1, SW26.1, SW41.1, SW56.1, SW70.1, SW80.1, U1.15 (GPIO11)
COL11: SW11.1, SW27.1, SW42.1, SW57.1, SW71.1, SW81.1, U1.16 (GPIO12)
COL12: SW12.1, SW28.1, SW43.1, SW58.1, SW72.1, SW82.1, U1.17 (GPIO13)
COL13: SW13.1, SW29.1, SW44.1, U1.19 (GPIO14)
COL14: SW30.1, SW45.1, SW59.1, SW73.1, SW83.1, U1.20 (GPIO15)
COL15: SW31.1, SW46.1, SW60.1, SW74.1, SW84.1, U1.21 (GPIO16)
GND: C1.2, C2.2, C3.2, C4.2, C5.2, C6.2, C7.2, C8.2, C9.2, C10.2, C11.2, C12.2, C13.2, C14.2, C15.2, C16.2, C17.2, C18.2, C19.2, C20.2, C21.2, C22.2, C23.2, C24.2, C25.2, C26.2, C27.2, C28.2, C29.2, C30.2, C31.2, C32.2, C33.2, C34.2, C35.2, C36.2, C37.2, C38.2, C39.2, C40.2, C41.2, C42.2, C44.2, C45.2, C46.2, C47.2, C48.2, C49.2, C50.2, C51.2, C52.2, C53.2, C54.2, C55.2, C56.2, C57.2, C58.2, C59.2, C60.2, C61.2, C62.2, C63.2, C64.2, C65.2, C66.2, C67.2, C68.2, C69.2, C70.2, C71.2, C72.2, C73.2, C74.2, C75.2, C76.2, C77.2, C78.2, C79.2, C80.2, C81.2, C82.2, C83.2, D14.2 (VSS), D15.2 (VSS), D16.2 (VSS), D85.2 (VSS), D86.2 (VSS), D87.2 (VSS), D88.2 (VSS), D89.2 (VSS), D90.2 (VSS), D91.2 (VSS), D92.2 (VSS), D93.2 (VSS), D94.2 (VSS), D95.2 (VSS), D96.2 (VSS), D97.2 (VSS), D98.2 (VSS), D99.2 (VSS), D100.2 (VSS), D101.2 (VSS), D102.2 (VSS), D103.2 (VSS), D104.2 (VSS), D105.2 (VSS), D106.2 (VSS), D107.2 (VSS), D108.2 (VSS), D109.2 (VSS), D110.2 (VSS), D111.2 (VSS), D112.2 (VSS), D113.2 (VSS), D114.2 (VSS), D115.2 (VSS), D116.2 (VSS), D117.2 (VSS), D118.2 (VSS), D119.2 (VSS), D120.2 (VSS), D121.2 (VSS), D122.2 (VSS), D123.2 (VSS), D124.2 (VSS), D125.2 (VSS), D126.2 (VSS), D127.2 (VSS), D128.2 (VSS), D129.2 (VSS), D130.2 (VSS), D131.2 (VSS), D132.2 (VSS), D133.2 (VSS), D134.2 (VSS), D135.2 (VSS), D136.2 (VSS), D137.2 (VSS), D138.2 (VSS), D139.2 (VSS), D140.2 (VSS), D141.2 (VSS), D142.2 (VSS), D143.2 (VSS), D144.2 (VSS), D145.2 (VSS), D146.2 (VSS), D147.2 (VSS), D148.2 (VSS), D149.2 (VSS), D150.2 (VSS), D151.2 (VSS), D152.2 (VSS), D153.2 (VSS), D154.2 (VSS), D155.2 (VSS), D156.2 (VSS), D157.2 (VSS), D158.2 (VSS), D159.2 (VSS), D160.2 (VSS), D161.2 (VSS), D162.2 (VSS), D163.2 (VSS), D164.2 (VSS), U1.3 (GND), U1.8 (GND), U1.13 (GND), U1.18 (GND), U1.23 (GND), U1.28 (GND), U1.38 (GND); also elsewhere on the board
LED: D14.3 (DIN), U1.29 (GPIO22)
unnamed: D1.2 (A), SW1.2
unnamed: D2.2 (A), SW2.2
unnamed: D3.2 (A), SW3.2
unnamed: D4.2 (A), SW4.2
unnamed: D5.2 (A), SW5.2
unnamed: D6.2 (A), SW6.2
unnamed: D7.2 (A), SW7.2
unnamed: D8.2 (A), SW8.2
unnamed: D9.2 (A), SW9.2
unnamed: D10.2 (A), SW10.2
unnamed: D11.2 (A), SW11.2
unnamed: D12.2 (A), SW12.2
unnamed: D13.2 (A), SW13.2
unnamed: D14.1 (DOUT), D15.3 (DIN)
unnamed: D15.1 (DOUT), D16.3 (DIN)
unnamed: D16.1 (DOUT), D85.3 (DIN)
unnamed: D17.2 (A), SW17.2
unnamed: D18.2 (A), SW18.2
unnamed: D19.2 (A), SW19.2
unnamed: D20.2 (A), SW20.2
unnamed: D21.2 (A), SW21.2
unnamed: D22.2 (A), SW22.2
unnamed: D23.2 (A), SW23.2
unnamed: D24.2 (A), SW24.2
unnamed: D25.2 (A), SW25.2
unnamed: D26.2 (A), SW26.2
unnamed: D27.2 (A), SW27.2
unnamed: D28.2 (A), SW28.2
unnamed: D29.2 (A), SW29.2
unnamed: D30.2 (A), SW30.2
unnamed: D31.2 (A), SW31.2
unnamed: D32.2 (A), SW32.2
unnamed: D33.2 (A), SW33.2
unnamed: D34.2 (A), SW34.2
unnamed: D35.2 (A), SW35.2
unnamed: D36.2 (A), SW36.2
unnamed: D37.2 (A), SW37.2
unnamed: D38.2 (A), SW38.2
unnamed: D39.2 (A), SW39.2
unnamed: D40.2 (A), SW40.2
unnamed: D41.2 (A), SW41.2
unnamed: D42.2 (A), SW42.2
unnamed: D43.2 (A), SW43.2
unnamed: D44.2 (A), SW44.2
unnamed: D45.2 (A), SW45.2
unnamed: D46.2 (A), SW46.2
unnamed: D47.2 (A), SW47.2
unnamed: D48.2 (A), SW48.2
unnamed: D49.2 (A), SW49.2
unnamed: D50.2 (A), SW50.2
unnamed: D51.2 (A), SW51.2
unnamed: D52.2 (A), SW52.2
unnamed: D53.2 (A), SW53.2
unnamed: D54.2 (A), SW54.2
unnamed: D55.2 (A), SW55.2
unnamed: D56.2 (A), SW56.2
unnamed: D57.2 (A), SW57.2
unnamed: D58.2 (A), SW58.2
unnamed: D59.2 (A), SW59.2
unnamed: D60.2 (A), SW60.2
unnamed: D61.2 (A), SW61.2
unnamed: D62.2 (A), SW62.2
unnamed: D63.2 (A), SW63.2
unnamed: D64.2 (A), SW64.2
unnamed: D65.2 (A), SW65.2
unnamed: D66.2 (A), SW66.2
unnamed: D67.2 (A), SW67.2
unnamed: D68.2 (A), SW68.2
unnamed: D69.2 (A), SW69.2
unnamed: D70.2 (A), SW70.2
unnamed: D71.2 (A), SW71.2
unnamed: D72.2 (A), SW72.2
unnamed: D73.2 (A), SW73.2
unnamed: D74.2 (A), SW74.2
unnamed: D75.2 (A), SW75.2
unnamed: D76.2 (A), SW76.2
unnamed: D77.2 (A), SW77.2
unnamed: D78.2 (A), SW78.2
unnamed: D79.2 (A), SW79.2
unnamed: D80.2 (A), SW80.2
unnamed: D81.2 (A), SW81.2
unnamed: D82.2 (A), SW82.2
unnamed: D83.2 (A), SW83.2
unnamed: D84.2 (A), SW84.2
unnamed: D85.1 (DOUT), D86.3 (DIN)
unnamed: D86.1 (DOUT), D87.3 (DIN)
unnamed: D87.1 (DOUT), D88.3 (DIN)
unnamed: D88.1 (DOUT), D89.3 (DIN)
unnamed: D89.1 (DOUT), D90.3 (DIN)
unnamed: D90.1 (DOUT), D91.3 (DIN)
unnamed: D91.1 (DOUT), D92.3 (DIN)
unnamed: D92.1 (DOUT), D93.3 (DIN)
unnamed: D93.1 (DOUT), D94.3 (DIN)
unnamed: D94.1 (DOUT), D95.3 (DIN)
unnamed: D95.1 (DOUT), D96.3 (DIN)
unnamed: D96.1 (DOUT), D97.3 (DIN)
unnamed: D97.1 (DOUT), D98.3 (DIN)
unnamed: D98.1 (DOUT), D99.3 (DIN)
unnamed: D99.1 (DOUT), D100.3 (DIN)
unnamed: D100.1 (DOUT), D101.3 (DIN)
unnamed: D101.1 (DOUT), D102.3 (DIN)
unnamed: D102.1 (DOUT), D103.3 (DIN)
unnamed: D103.1 (DOUT), D104.3 (DIN)
unnamed: D104.1 (DOUT), D105.3 (DIN)
unnamed: D105.1 (DOUT), D106.3 (DIN)
unnamed: D106.1 (DOUT), D107.3 (DIN)
unnamed: D107.1 (DOUT), D108.3 (DIN)
unnamed: D108.1 (DOUT), D109.3 (DIN)
unnamed: D109.1 (DOUT), D110.3 (DIN)
unnamed: D110.1 (DOUT), D111.3 (DIN)
unnamed: D111.1 (DOUT), D112.3 (DIN)
unnamed: D112.1 (DOUT), D113.3 (DIN)
unnamed: D113.1 (DOUT), D114.3 (DIN)
unnamed: D114.1 (DOUT), D115.3 (DIN)
unnamed: D115.1 (DOUT), D116.3 (DIN)
unnamed: D116.1 (DOUT), D117.3 (DIN)
unnamed: D117.1 (DOUT), D118.3 (DIN)
unnamed: D118.1 (DOUT), D119.3 (DIN)
unnamed: D119.1 (DOUT), D120.3 (DIN)
unnamed: D120.1 (DOUT), D121.3 (DIN)
unnamed: D121.1 (DOUT), D122.3 (DIN)
unnamed: D122.1 (DOUT), D123.3 (DIN)
unnamed: D123.1 (DOUT), D124.3 (DIN)
unnamed: D124.1 (DOUT), D125.3 (DIN)
unnamed: D125.1 (DOUT), D126.3 (DIN)
unnamed: D126.1 (DOUT), D127.3 (DIN)
unnamed: D127.1 (DOUT), D128.3 (DIN)
unnamed: D128.1 (DOUT), D129.3 (DIN)
unnamed: D129.1 (DOUT), D130.3 (DIN)
unnamed: D130.1 (DOUT), D131.3 (DIN)
unnamed: D131.1 (DOUT), D132.3 (DIN)
unnamed: D132.1 (DOUT), D133.3 (DIN)
unnamed: D133.1 (DOUT), D134.3 (DIN)
unnamed: D134.1 (DOUT), D135.3 (DIN)
unnamed: D135.1 (DOUT), D136.3 (DIN)
unnamed: D136.1 (DOUT), D137.3 (DIN)
unnamed: D137.1 (DOUT), D138.3 (DIN)
unnamed: D138.1 (DOUT), D139.3 (DIN)
unnamed: D139.1 (DOUT), D140.3 (DIN)
unnamed: D140.1 (DOUT), D141.3 (DIN)
unnamed: D141.1 (DOUT), D142.3 (DIN)
unnamed: D142.1 (DOUT), D143.3 (DIN)
unnamed: D143.1 (DOUT), D144.3 (DIN)
unnamed: D144.1 (DOUT), D145.3 (DIN)
unnamed: D145.1 (DOUT), D146.3 (DIN)
unnamed: D146.1 (DOUT), D147.3 (DIN)
unnamed: D147.1 (DOUT), D148.3 (DIN)
unnamed: D148.1 (DOUT), D149.3 (DIN)
unnamed: D149.1 (DOUT), D150.3 (DIN)
unnamed: D150.1 (DOUT), D151.3 (DIN)
unnamed: D151.1 (DOUT), D152.3 (DIN)
unnamed: D152.1 (DOUT), D153.3 (DIN)
unnamed: D153.1 (DOUT), D154.3 (DIN)
unnamed: D154.1 (DOUT), D155.3 (DIN)
unnamed: D155.1 (DOUT), D156.3 (DIN)
unnamed: D156.1 (DOUT), D157.3 (DIN)
unnamed: D157.1 (DOUT), D158.3 (DIN)
unnamed: D158.1 (DOUT), D159.3 (DIN)
unnamed: D159.1 (DOUT), D160.3 (DIN)
unnamed: D160.1 (DOUT), D161.3 (DIN)
unnamed: D161.1 (DOUT), D162.3 (DIN)
unnamed: D162.1 (DOUT), D163.3 (DIN)
unnamed: D163.1 (DOUT), D164.3 (DIN)
ROW1: D1.1 (K), D2.1 (K), D3.1 (K), D4.1 (K), D5.1 (K), D6.1 (K), D7.1 (K), D8.1 (K), D9.1 (K), D10.1 (K), D11.1 (K), D12.1 (K), D13.1 (K), U1.24 (GPIO18)
ROW2: D17.1 (K), D18.1 (K), D19.1 (K), D20.1 (K), D21.1 (K), D22.1 (K), D23.1 (K), D24.1 (K), D25.1 (K), D26.1 (K), D27.1 (K), D28.1 (K), D29.1 (K), D30.1 (K), D31.1 (K), U1.25 (GPIO19)
ROW3: D32.1 (K), D33.1 (K), D34.1 (K), D35.1 (K), D36.1 (K), D37.1 (K), D38.1 (K), D39.1 (K), D40.1 (K), D41.1 (K), D42.1 (K), D43.1 (K), D44.1 (K), D45.1 (K), D46.1 (K), U1.26 (GPIO20)
ROW4: D47.1 (K), D48.1 (K), D49.1 (K), D50.1 (K), D51.1 (K), D52.1 (K), D53.1 (K), D54.1 (K), D55.1 (K), D56.1 (K), D57.1 (K), D58.1 (K), D59.1 (K), D60.1 (K), U1.27 (GPIO21)
ROW5: D61.1 (K), D62.1 (K), D63.1 (K), D64.1 (K), D65.1 (K), D66.1 (K), D67.1 (K), D68.1 (K), D69.1 (K), D70.1 (K), D71.1 (K), D72.1 (K), D73.1 (K), D74.1 (K), U1.31 (GPIO26_ADC0)
ROW6: D75.1 (K), D76.1 (K), D77.1 (K), D78.1 (K), D79.1 (K), D80.1 (K), D81.1 (K), D82.1 (K), D83.1 (K), D84.1 (K), U1.32 (GPIO27_ADC1)

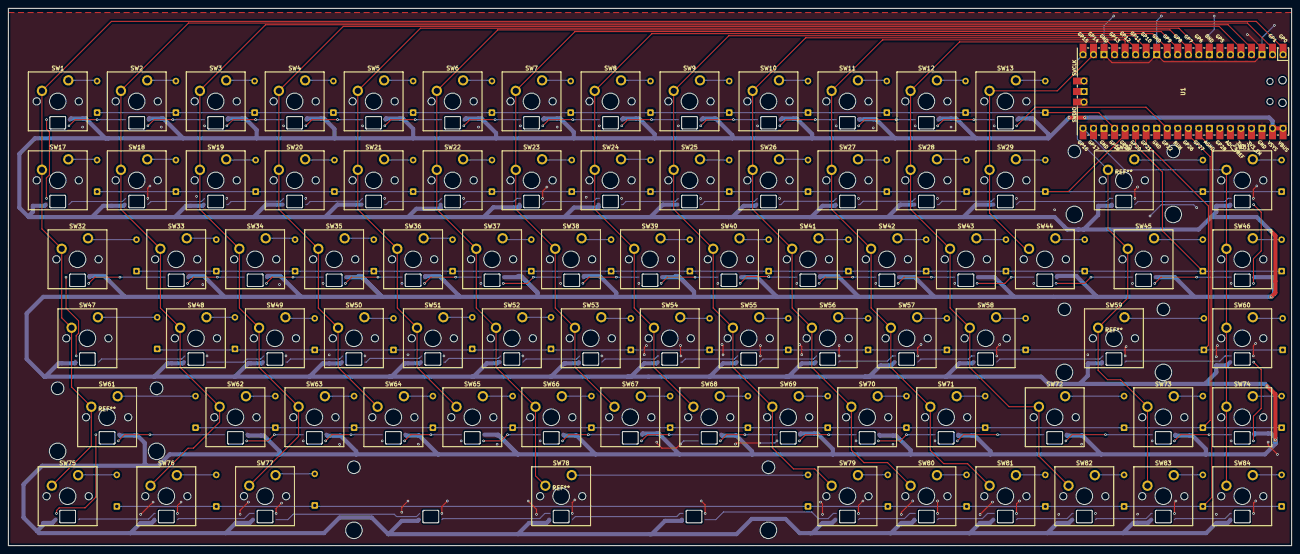
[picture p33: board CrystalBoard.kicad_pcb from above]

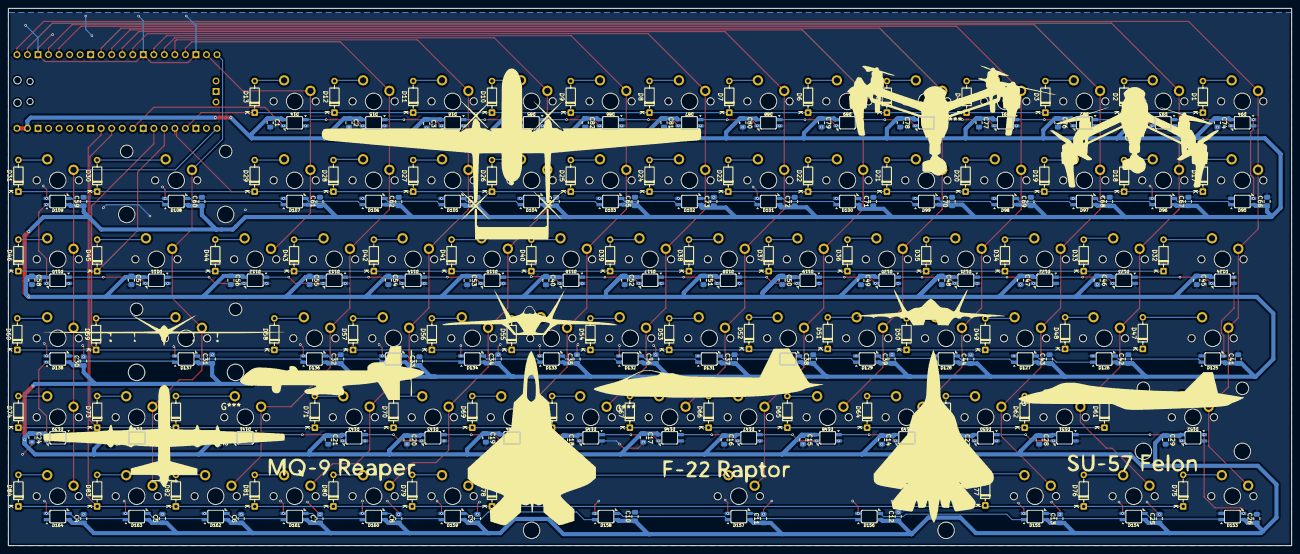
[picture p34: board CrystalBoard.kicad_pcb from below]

Board: 2 copper layers, 309.6 x 129.6 mm, 329 parts (247 on the bottom side), 187 nets.

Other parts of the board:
C43: C; C_0805_2012Metric_Pad1.18x1.45mm_HandSolder

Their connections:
+5V: C43.1; also elsewhere on the board
GND: C43.2; also elsewhere on the board

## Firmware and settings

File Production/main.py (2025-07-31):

import board
from kmk.kmk_keyboard import KMKKeyboard
from kmk.keys import KC
from kmk.scanners import DiodeOrientation
from kmk.modules.macros import Macros
from kmk.modules.mouse_keys import MouseKeys
from kmk.modules.layers import Layers
from kmk.extensions.media_keys import MediaKeys
from kmk.extensions.RGB import RGB
from kmk.extensions.rgb import AnimationModes

keyboard = KMKKeyboard()

# — Modules & Extensions —
macros = Macros()
keyboard.modules.append(macros)
keyboard.modules.append(MouseKeys())
keyboard.modules.append(Layers())
keyboard.extensions.append(MediaKeys())

# RGB: adjust pixel_pin & num_pixels if yours differ
rgb = RGB(
    pixel_pin=board.D22,
    num_pixels=87,
    animation_speed=1,
    animation_mode=AnimationModes.STATIC,
    val_default=30,
    val_limit=40
)
keyboard.extensions.append(rgb)

# — Matrix pinout (15 cols × 6 rows) —
keyboard.col_pins = (
    board.D0,  board.D1,  board.D2,  board.D3,  board.D6,
    board.D7,  board.D8,  board.D9,  board.D10, board.D11,
    board.D12, board.D13, board.D14, board.D15, board.D16
)
keyboard.row_pins = (
    board.D18, board.D19, board.D20,
    board.D21, board.D26, board.D27
)
keyboard.diode_orientation = DiodeOrientation.COL2ROW

keyboard.keymap = [
    [
        KC.ESC,  KC.F1,  KC.F2,  KC.F3,  KC.F4,  KC.F5,  KC.F6,  KC.F7,  KC.F8,  KC.F9, 
        KC.F10, KC.F11, KC.F12, KC.BSPC, KC.HOME,
        
        KC.GRV, KC.N1,  KC.N2,  KC.N3,  KC.N4,  KC.N5,  KC.N6,  KC.N7,  KC.N8,  KC.N9, 
        KC.N0,  KC.MINS,KC.EQL, KC.BSLS, KC.PGUP,
        
        KC.TAB, KC.Q,   KC.W,   KC.E,   KC.R,   KC.T,   KC.Y,   KC.U,   KC.I,   KC.O, 
        KC.P,   KC.LBRC,KC.RBRC,KC.ENT, KC.PGDN,
        
        KC.CAPS,KC.A,   KC.S,   KC.D,   KC.F,   KC.G,   KC.H,   KC.J,   KC.K,   KC.L, 
        KC.SCLN,KC.QUOT,KC.NO,  KC.NO,  KC.END,
        
        KC.LSFT,KC.Z,   KC.X,   KC.C,   KC.V,   KC.B,   KC.N,   KC.M,   KC.COMM,KC.DOT, 
        KC.SLSH,KC.NO,  KC.NO,  KC.RSFT,KC.UP,
        
        KC.LCTRL,KC.LGUI,KC.LALT,KC.SPC, KC.RALT,KC.RGUI,KC.RCTL,KC.LEFT,KC.DOWN,KC.RIGHT
    ],
    
    # Fn layer
    [
        KC.ESC , KC.F1  , KC.F2  , KC.F3  , KC.F4  , KC.F5  , KC.F6  , KC.F7  , KC.F8  , KC.F9  , KC.F10 , KC.F11 , KC.F12 , KC.TRNS, KC.TRNS,
        KC.TRNS, KC.TRNS, KC.TRNS, KC.TRNS, KC.TRNS, KC.TRNS, KC.TRNS, KC.TRNS, KC.TRNS, KC.TRNS, KC.TRNS, KC.TRNS, KC.TRNS, KC.TRNS, KC.TRNS,
        KC.TRNS, KC.TRNS, KC.TRNS, KC.TRNS, KC.TRNS, KC.TRNS, KC.TRNS, KC.TRNS, KC.TRNS, KC.TRNS, KC.TRNS, KC.TRNS, KC.TRNS, KC.TRNS, KC.TRNS, 
        KC.TRNS, KC.TRNS, KC.TRNS, KC.TRNS, KC.TRNS, KC.TRNS, KC.TRNS, KC.TRNS, KC.TRNS, KC.TRNS, KC.TRNS, KC.TRNS, KC.TRNS, KC.TRNS, KC.TRNS,
        KC.TRNS, KC.TRNS, KC.TRNS, KC.TRNS, KC.TRNS, KC.TRNS, KC.TRNS, KC.TRNS, KC.TRNS, KC.TRNS, KC.TRNS, KC.TRNS, KC.TRNS, KC.TRNS, KC.TRNS,
        KC.TRNS, KC.TRNS, KC.TRNS, KC.TRNS, KC.TRNS, KC.TRNS, KC.TRNS, KC.TRNS, KC.TRNS, KC.TRNS, KC.TRNS, KC.TRNS, KC.TRNS, KC.TRNS, KC.TRNS,
    ]
]

if __name__ == '__main__':
    keyboard.go()

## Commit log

2025-07-31 added the dxf files that I made for the Laser cutting of acrylic sheets
    [Bottom.dxf, ClosedSpacer.dxf, OpenSpacer.dxf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]
2025-07-31 Added the Kicad Project Files
    [CrystalBoard.kicad_pcb, CrystalBoard.kicad_sch]
2025-07-31 added the Production Folder with the ZIP folder of PCBs
    [Bottom.dxf, ClosedSpacer.dxf, OpenSpacer.dxf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]
2025-07-31 added the BOM file
    [BOM.csv]
2025-07-31 Final Commit
    [BOM.csv]
2025-08-05 Final Update for re-review
    [BOM.csv]
2025-08-05 One more Update for re-review
    [CrystalBoard.kicad_pcb, CrystalBoard.kicad_sch]
2025-08-12 Re-review 2 by Kai, suggesting to make the Case bit more complex. So implemented a different approach to make the case with a referrence.
    [ClosedSpacerLevel1.dxf, ClosedSpacerLevel2.dxf, Full Keyboard Updated_.step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]
2025-08-14 added capacitors to the BOM
